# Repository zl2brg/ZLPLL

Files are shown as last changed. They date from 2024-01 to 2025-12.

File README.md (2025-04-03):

# ZLPLL
Wayne Knowles ZL2BKC ZLPLL ZLPLL-14G Code. Imported v4.2A from his avrstudio project and added open source licences along with Linux Makefile build support.
v4.4A Fixed floating point precision register calculation inaccuracies by moving to 64/32bit integer math. 
Register calculations are based on Andy G4JNT's code. Frequency calculation now accurate to 10Hz below 6.8Ghz and 20Hz above.

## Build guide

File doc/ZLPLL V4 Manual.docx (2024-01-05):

# ZLPLL User Guide

Wayne Knowles, ZL2BKC

w.knowles@xtra.co.nz

<< Update Picture >>

# 1 Introduction

The ZLPLL is a frequency agile synthesizer with many unique features designed for use as a local oscillator for amateur radio projects, weak signal source, or an exciter for a CW beacon.

Two versions of the board are currently available depending on frequency requirements with an onboard microprocessor catering for simple configuration of up to 16 frequencies that can be programmed by the end user over a serial interface.

As the programming and interfacing details are similar they are both included in this manual with specific differences between the boards highlighted where appropriate.

# 2 Specifications

Model | ZLPLL TCXO | ZLPLL 14G
PLL | ADF4351 | ADF5355
Frequency Range | 31MHz – 4.4GHz | 62MHz – 13.8GHz (14 GHz with reduced specs)
Power | 8 to 14VDC 150mA | 9 to 14VDC 300mA
Onboard Reference | 26MHz TCXO | None
Stability | Typically +/- 100Hz at 1GHz after 2 minute warmup | Governed by external reference
External Reference | +0dBm to +10dBm Frequency: 10MHz (Default) Custom frequency between 5 and 100MHz set in firmware | +0dBm to +10dBm Frequency: 10MHz (Default) Custom frequency between 5 and 200MHz set in firmware
Phase Noise | Typical Phase noise at 1GHz -85dBc at 100Hz -98dBc at 1kHz -98dBc at 10kHz -106dBc at 100kHz -138dBc at 1MHz | Typical Phase noise at 10GHz
Outputs | 2 outputs at the programmed frequency, 180 degrees apart. | Output 1 = RF Out for 6.8 to 13.4 GHz Output2 = RF Out for 62MHz to 6.8GHz
Output Level | 4 software selectable levels: -3dBm/0dBm/+3dBm and +6dBm | Above 6.8GHz output: Fixed +10dBm to +14dBm Below 6.8GHz output: +7dBm to 2GHz 0dBm at 5.7GHz
Provision for MMIC Amplifier | Yes (SOT-86) on output RF1 Only | No
CW Beacon Exciter Mode | Yes | Yes
Selectable Channels | 16 (Jumpers or BCD Interface) | 16 (Jumpers or BCD Interface)
Frequency Resolution | 1 KHz | 1 KHz (1 Hz planned for a future firmware version)

# 3 ZLPLL TCXO (ADF4351) Performance

## 3.1 Phase Noise

< Updated Picture >

Figure 1 Performance

## 3.2 Output Level

The Output level is dependent on the choice of inductor value in the output stage. The default 8.2nH inductors are suitable for frequency ranges above 1GHz and driving external multipliers.

For applications below 1GHz the inductor can be changed to 47nH which improves the output level for directly driving level 7 mixers up to 2GHz. This optional inductor is supplied with the board and can be fitted on request.

## 3.3 Harmonic Level

The following graph can be used as a guide to determine the level of output for harmonics. As a general rule the lowest odd harmonic should be used to when wanting the highest level output on a given frequency.

## 3.4 Stability

Because the ZLPLL uses an oven controlled xtal oscillator (OCXO) it has excellent frequency stability making this suitable for use on WSJT modes which require excellent stability over a 309 second to 1 minute period (depending on the mode being used).

With stability better than 1x10⁻¹⁰ the frequency error sufficiently allows for reliable frequency operation using all modes (including WSJT) up to 10GHz and potentially higher.

For more stringent frequency requirements an external oscillator such as Rubidium or GPSDO and the stability will be governed by the external reference.

# 4 ZLPLL TCXO (ADF5355) Performance

## 4.1 Phase Noise

Figure 1 Performance

## 4.2 Output Level

# 5 Application Notes

## 5.1 Termination

Ensure both outputs are well matched. If the 2nd output is un-used it should be terminated otherwise oscillations will occur especially at high output levels (L2 and L3).

## 5.2 Power Supply

The on board voltage regulator is capable of operating up to 15V supply voltage. However for supply voltage above 9V the regulator will get very hot and it is advised to solder a small copper or brass strip to improve the heat dissipation.

## 5.3 Warm-up

The recommended warm-up time is 5 minutes after applying power. For applications that demand short to medium term stability such as WSJT modes a warm-up period of 30 minutes is recommended.

When using an external reference no warm-up is required as stability is governed by the external reference.

# 6 Features

## 6.1 Frequency Multiplier Correction

In cases where the LO is followed by a frequency multiplier, in particular when multiplying by an odd number, the resulting frequency may suffer from rounding errors resulting in a small frequency error in the final frequency.

In order to prevent oddball frequencies (eg with 0.3333333 MHz re-occurring) the correct procedure is to set the ‘mult’ multiplier value to 3 and then program in desired frequency for the 3rd harmonic.

Due to limitations of the 8 bit Atmel processor only single precision math is supported in firmware various rounding errors occur after 76 significant digits. To overcome this restriction the “step” parameter can be set to force the rounding to the specified frequency step value. As this workaround is not completely failsafe final confirmation using a frequency counter is recommended if ultimate accuracy is required.

Example: Generate a Frequency of 10368.280 MHz for a beacon using the 3rd Harmonic

mult 3

step 10000

freq 10368.280

save 0

Note: The frequency entered is the final frequency of the harmonic.

## 6.2 Channel Interface

## 6.3 Programming

Programming can be done by connecting a TTL level RS232 interface onto the following pins of J4:

RXD, TXD, and GND

Baud rate: 9600 8 bits No Parity 1 stop bit

The interface levels are 3.3V but the protection circuits allow for 5V levels to also be connected without damage.

A suitable interface is a PL2303 based USB to RS232 converter, or a programming cable for a Yaesu FT8x7 transceiver.

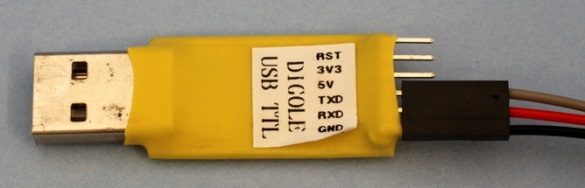
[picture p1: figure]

The labeling of the pins on J4 assumes a DCE interface, thus the RXD pin is an input, and TXD is an output.

Use any terminal program, either TeraTerm, Putty or Hyperterm can be used.

uLO Universal Local Oscillator Rev3.1

(C)2012 W. Knowles, ZL2BKC

d

RF= 1152.000, L=3

Ref= 26.000, N= 0.025

ExtRef= 10.000

Params=23, CP=7

0 RF= 1152.000, L=3

1 RF= 1296.050, L=3

2 RF= 2400.050, L=3

3 RF= 3400.050, L=3

4 RF= 5760.050, L=3, M=3

5 RF=10368.050, L=3, M=3

6 RF= NAN, L=3, M=63

7 RF= 1242.000, L=3

8 RF= 4400.000, L=3

9 RF= NAN, L=3, M=63

10 RF= NAN, L=3, M=63

11 RF= NAN, L=3, M=63

12 RF= NAN, L=3, M=63

13 RF= NAN, L=3, M=63

14 RF= NAN, L=3, M=63

15 RF= NAN, L=3, M=63

The following example demonstrates the commands required to program channel 0 (the default if no channel switch installed) for 1920MHz:

M1

L3

F1920

S0

## 6.4 Command Reference

Note: Commands are not case sensitive

Command | Units | Description
freq ##.# | MHz | Set the output frequency to the specified value in MHz. Decimal numbers are permitted
level # | | Set the output attenuator level. 0 = Minimum (typically -3dBm) 1 = typically 0dBm 2 = typically +3dBm 3 = Maximum (typically +6dBm) Note for the >6.8GHz output on the ZLPLL14G board the level command is ignored and maximum output level is generated, typically > +10dBm
mode # | | Set operating mode. 0 = RF Output disabled 1 = RF Output Enabled (LO Mode) 2 = CW Beacon mode. RF Output keyed with message 3 = CW Beacon mode. RF Output enabled with external keying
save # | | Save current setup to memory channel #
channel # | | Recall settings from memory channel #
ref_int ## | MHz | Set frequency of internal reference. For ZLPLL this should be set to 26 MHz
ref_ext ## | MHz | Set frequency of external reference in MHz. Default frequency is 10 MHz, but can be changed to any value between 5 and 100MHz
show | | Display current configuration details
step # | Hz | Not supported
rdiv # | | Reference frequency divisor. This should be set to 1 unless the loop filter components have been changed.
config mtld # | | Mute to lock detect option. If the PLL is unlocked the RF Output will be disabled. 0=MTLD disabled 1=MTLD enabled
config spur # | | Spur reduction mode 0 = Spur reduction disabled (lower Phase Noise) 1 = Spur reduction enabled (higher pahse noise)
config bleed # | | ZLPLL 14G Only: Configure the loop filter bleed current. Value is typically between 10 and 20 for best performance
config cp # | | Phase Detector charge pump current.
config dblr_max # | | Frequency which the internal doubler is enabled on the reference input (either internal or external). Refer to the PLL datasheet
config ref_level # | | Sensitivity level for external reference input. Default value = 10
cw text | | Enter the CW Message used for beacon mode transmissions (using mode=2 or mode=3)
cal | | Enter TCXO Calibration routine.
adc | | Diagnostic: Show levels of ADC input pins
diag | | Diagnostic: Display PLL register values and frequency errors

Note the frequency changes are volatile and must be saved using the save command if you require settings to be persistent.

## 6.5 Frequency Calibration

## 6.6 Diagnostics

The ADC command dumps the measured voltages of the

## 6.7 Status LED’s

LED | Name | Colour | Description
LED1 | Aux | Amber | Power Up Permanently on to indicate self test failed Standard LO Mode Indicates the External Reference has been selected CW Mode Flashes to indicate the Key Down condition
LED2 | Lock | Green | Indicates the PLL is in a locked condition

At power up the Lock LED will flash 3 times while running power up diagnostics. If the diagnostic passes the Green Lock LED will stay lit to indicate the PLL has passed self tests and is locked.

If any of the self tests fail the Amber Aux LED will stay permanently on and if the PLL has achieved Lock condition despite the fault the Green Lock LED will light.

For the TCXO version of the ZLPLL when an external reference is connected the Aux LED will flash for 3 seconds indicating the reference signal has been detected and stay lit to indicate the external reference has been detected. If a lock issue occurs using an external reference the firmware till revert back to the on board reference until it sees the reference removed and reapplied.

## 6.8 Initial Programming

Several parameters have default settings, and if they are accidentally overwritten the performance of the board may be limited.

To reprogram the default settings, enter:

Ext_ref 10

Int_ref 26

Freq 1152

Level 3

Save 0

# 7 Special Applications

The board is designed to cater for several end user applications. Some of the applications are outlined in this section.

## 7.1 TX Offset

For some applications the LO frequency needs to be changed during transmit, for example generating a 20MHz repeater offset for a 1296 to 144MHz transverter.

When the TX line (shared with RS232 input) is pulled low the channel number is automatically increased by 8, or decreased by 8 for channels above 8.

## 7.2 Sharing LO between 2 Tranverters

In order to reduce construction costs and maximize the use of space many constructors opt to share a single LO across multiple bands. Given the PLL board contains 2 LO outputs there is a natural instinct to use these for driving multiple transverters

If the LO frequency requirement is different for each transverter the TX input can be dropped to a logic LOW which results in 8 being added to the channel number, where the different LO frequency has been setup.

Note: The interface is 3.3V logic with a pull-up to logic 1. In most cases a suitable interface circuit may need to be added externally using a NPN transistor or similar.

# 8 Experimental Options

## 8.1 2nd RF Output

The ADF4351 PLL chip provides 2 outputs with a phase difference of 180°. To enable the 2nd output remove R18 and install a 1206 0R jumper into location LPF2 and install the SMA connector.

Parts to add this option are supplied with the board.

## 8.2 Low Frequency operation

The ADF4350 and ADF4351 datasheets recommend different output inductors depending on frequency range. If you require a few more dB of output on the lower frequencies then the inductors L4 and L5 can be changed as follows:

Frequency Range | L4 and L5 Inductor Values
137 to 500MHz | 100nH
500 to 1000MHz | 47nH
1000 to 2000MHz | 7.5nH
2000 to 4400MHz | 3.9nH

As supplied a 3.9nH inductor is installed suitable for > 2000 operation, and replacement inductors are supplied if more output power is required on lower frequencies.

Details of the expected power levels are shown in section 3.2

## 8.3 10MHz Filter Option

The external reference input at the PLL is a high impedance and extremely sensitive to external noise, or aliasing used on DDS reference. An optional 10MHz Xtal can be installed in location X1 if more filtering is required.

Note that the input resistor R10, 49.9Ω may be removed to increase level by 3dB .

## 8.4 Low Pass Filter

When driving a frequency multiplier the LO harmonics generated are critical for producing a large signal after multiplication. However there are design applications where no multiplication is required and if there is insufficient filtering before the mixer this can result in unwanted images. For such applications a Minicircuits LFCN series Low Pass filter can be substituted with the 0Ω 1206 jumper installed in location LPF1 and LPF2.

## 8.5 Disable on-board oscillator power-down

When an external reference is detected the internal oscillator is powered down for 2 reasons:

1. Power Reduction (saving approx. 50mA)
2. Reduce cross talk from internal oscillator which causes unwanted spurs

When the external oscillator is removed the internal reference starts from cold again and requires several minutes to warm-up, and 30 minutes to be become completely stable. By installing a 0Ω jumper in location R6 the internal reference is never powered off.

# 9 CW Beacon Firmware

All boards feature the CW Beacon firmware by default. This is enabled by selecting mode 2 which is saved as part of the memory channel configuration.

When the message finishes it will loop back to the beginning with no delay, so inserting a space or delay is recommended.

The maximum message length is 100 characters

2 special characters are used to control the carrier as follows

Character | Purpose
^ | Send 1 second with carrier down
_ (underscore) | Wait 1 second with no carrier

## 9.1 Special Considerations

Due to the high frequency of the PLL chipsets the RF output has an extremely fast rise/fall time which ultimately results in a wide bandwidth “glitch” which amateur radio stations refer to as key clicks. On lower bands with higher channel densities and intermod potential it is desirable to implement envelope shaping to control key clocks. This cannot be done by the ZLPLL itself, however timing signals are available to interface to external PA’s to control the RF envelope.

The timing parameter t1 and t2 set the delay are as follows

<< Diagram of key timing >>

When interfacing to an external

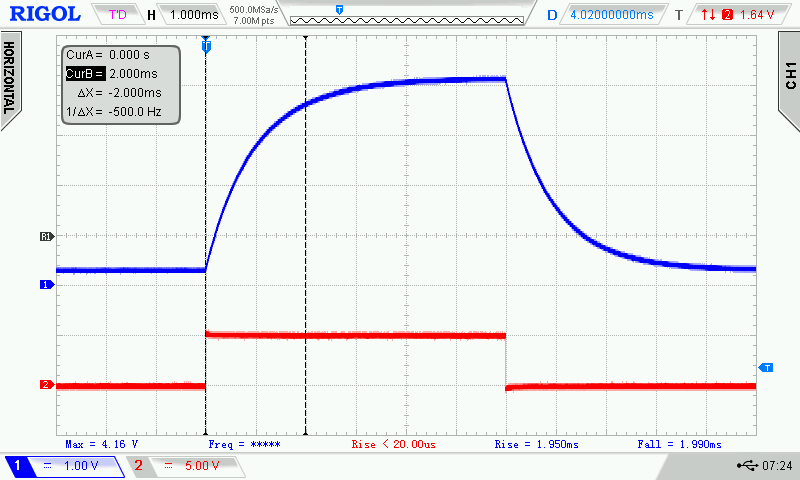
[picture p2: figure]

## 9.2 Configuration example

> cw text [ENTER]

_ZLPLL_EXAMPLE_^^^^^ [ENTER]

>

# 10 External Reference requirements

# 11 Application Notes

## 11.1 LO For 23cm Transverter

## 11.2 LO for 76GHz transverter

## 11.3 LO for 122GHz transverter

The narrowband segment of the 122GHz amateur band (2.5mm) starts at 122.250 GHz. One recommended lineup uses surplus 38GHz triplers (such as the CMA 38400 which operates at the required 40.7 GHz) and use the 3rd harmonic in the final mixer.

IF = 144MHz RF = 122250 MHz

Flo = 122106 MHz

FLO/3 (output of 38GHz module) = 40702 MHz

FLO/9 (input to 38GHz module) = 13567 1/3 MHz

In order to precisely configure this frequency the following setup is recommended:

freq 122106

multiplier 9

step 20000

save 0

For an IF of 145 MHz

freq 122105

multiplier 9

step 20000

save 0

## 11.4 CW Beacon

# 12 Troubleshooting

# 13 FAQ

## 13.1 Sometimes the frequency is displayed incorrectly

This is a side effect of the single precision math used in the on board micro. With careful use of the step parameter to round the frequency it is possible to control the output frequency however the displayed frequency as seen in the “show” output may be incorrect.

## 13.2 Heat Issues

## 13.3 Spurs

The onboard TXCO of the ZLPLL TCXO version is tuned using a PWM signal which can produce weak spurs about 50kHz each side of the programmed frequency. However they will disappear when using an external reference

Also you may see spurs at the harmonics of the reference frequency, especially if it falls within or near the loop bandwidth of the PLL.

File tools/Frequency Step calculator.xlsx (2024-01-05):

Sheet: Sheet1
Freq: | 2320.857 |  |  |  | 116.04285 | 2320
VCO= | 4641.714
 |  | H(Hz) | Div | Remainder
Div Start | 25 | 2.5e-05 | 92834280 | 0
 | 25.001 | 2.5001e-05 | 92830566.78 | 0.7773288935
 | 26.001 | 2.6001e-05 | 89260297.68 | 0.6808584183
 | 27.001 | 2.7001e-05 | 85954483.17 | 0.1672900915
 | 28.001 | 2.8001e-05 | 82884789.83 | 0.8289346695
 | 29.001 | 2.9001e-05 | 80026792.18 | 0.179580003
 | 30.001 | 3.0001e-05 | 77359321.36 | 0.3559547961
 | 31.001 | 3.1001e-05 | 74863939.87 | 0.8729073107
 | 32.001 | 3.2001e-05 | 72524514.86 | 0.85891065
 | 33.001 | 3.3001e-05 | 70326868.88 | 0.8827611208
 | 34.001 | 3.4001e-05 | 68258492.4 | 0.3972824216
 | 35.001 | 3.5001e-05 | 66308305.48 | 0.4769863635
 | 36.001 | 3.6001e-05 | 64466459.27 | 0.2650204077
 | 37.001 | 3.7001e-05 | 62724169.62 | 0.6170373634
 | 38.001 | 3.8001e-05 | 61073577.01 | 0.01113127917
 | 39.001 | 3.9001e-05 | 59507628.01 | 0.009538203478
 | 40.001 | 4.0001e-05 | 58019974.5 | 0.5006374866
 | 41.001 | 4.1001e-05 | 56604887.69 | 0.685666196
 | 42.001 | 4.2001e-05 | 55257184.35 | 0.3527534977
 | 43.001 | 4.3001e-05 | 53972163.44 | 0.4380595759
 | 44.001 | 4.4001e-05 | 52745551.24 | 0.2374718636
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

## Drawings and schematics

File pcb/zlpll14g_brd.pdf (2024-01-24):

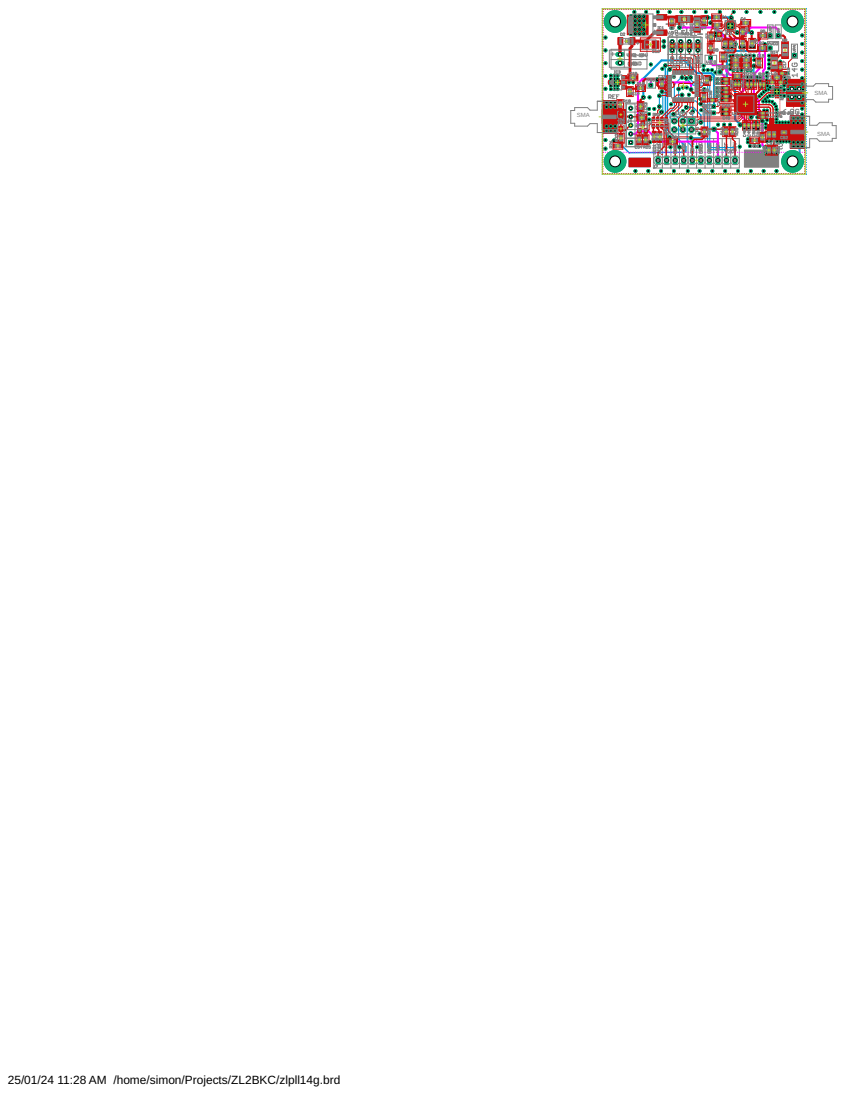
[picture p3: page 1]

25/01/24 11:28 AM /home/simon/Projects/ZL2BKC/zlpll14g.brd

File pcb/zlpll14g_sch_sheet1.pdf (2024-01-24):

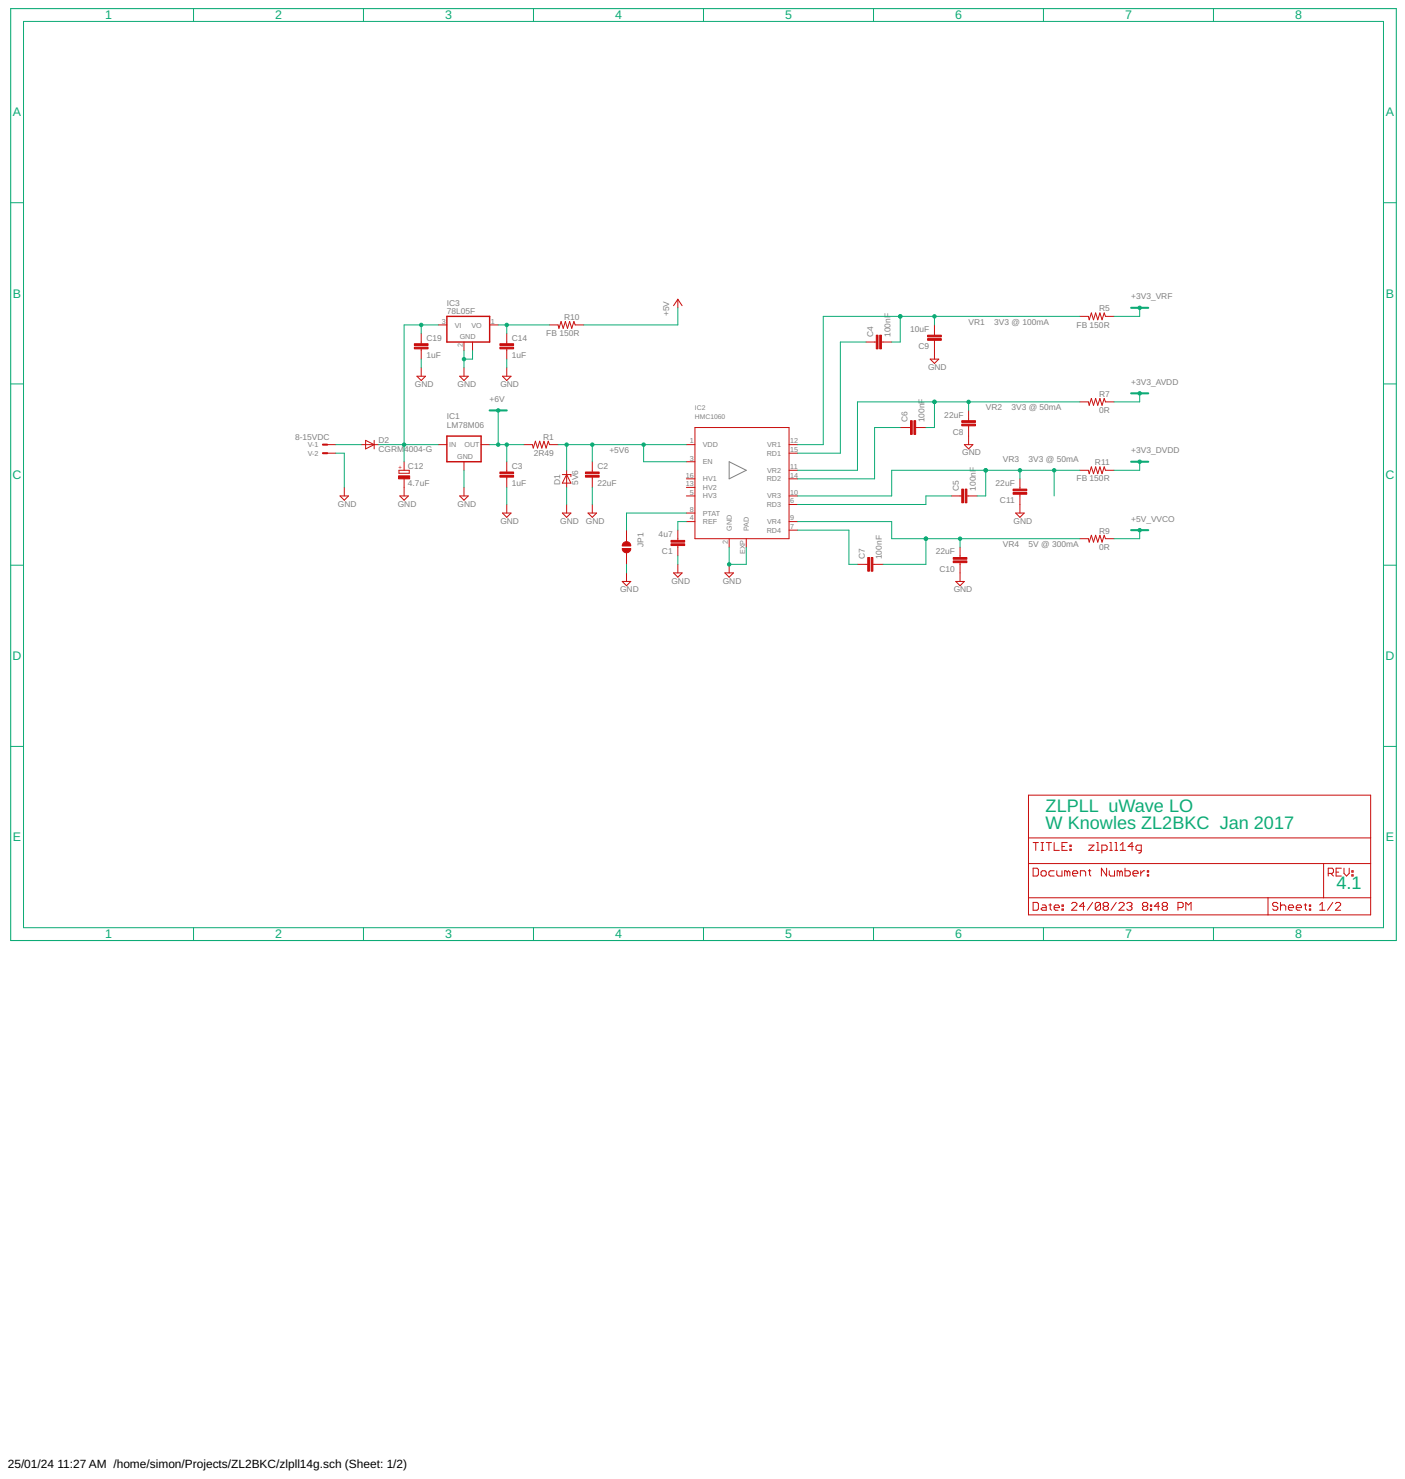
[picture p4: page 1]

25/01/24 11:27 AM /home/simon/Projects/ZL2BKC/zlpll14g.sch (Sheet: 1/2)

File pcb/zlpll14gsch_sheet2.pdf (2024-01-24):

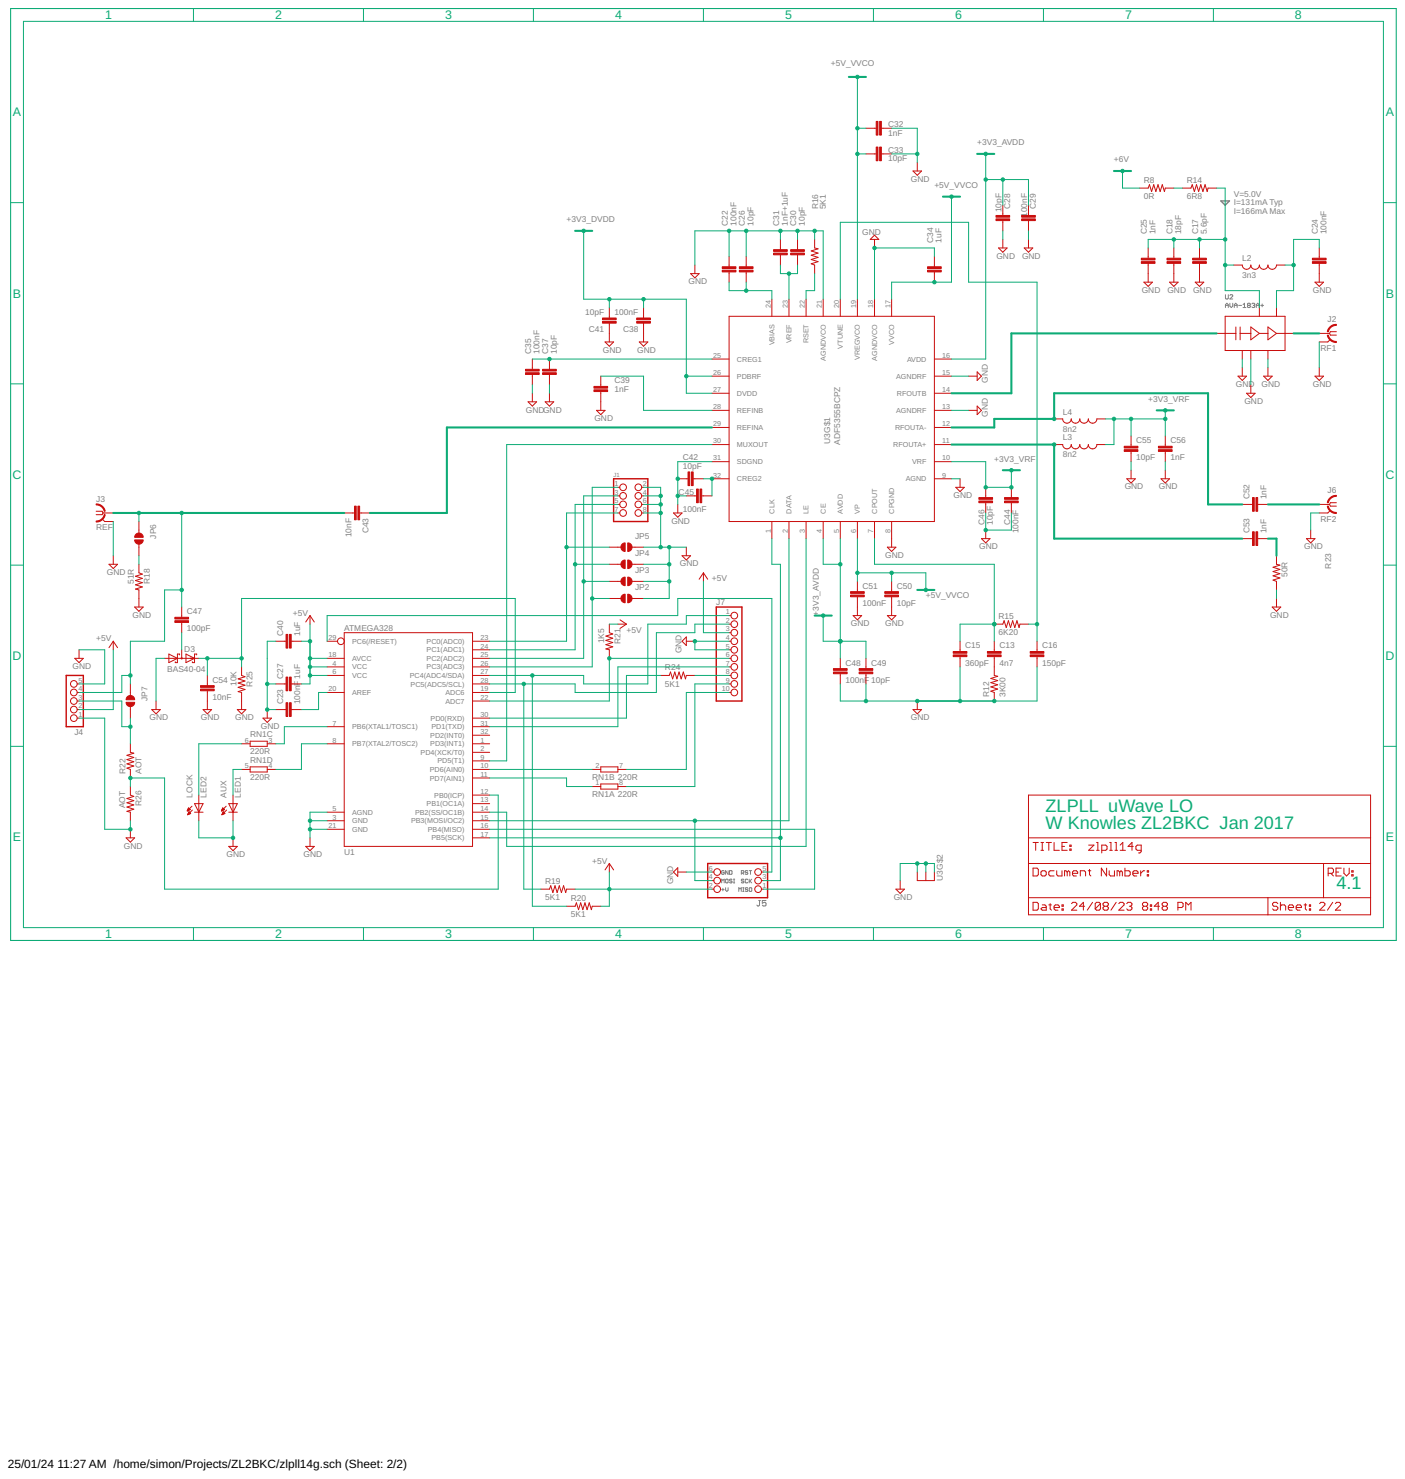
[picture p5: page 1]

+5V_VVCO

3 4
5 6
7 8

ATMEGA328 | | 2

25/01/24 11:27 AM /home/simon/Projects/ZL2BKC/zlpll14g.sch (Sheet: 2/2)

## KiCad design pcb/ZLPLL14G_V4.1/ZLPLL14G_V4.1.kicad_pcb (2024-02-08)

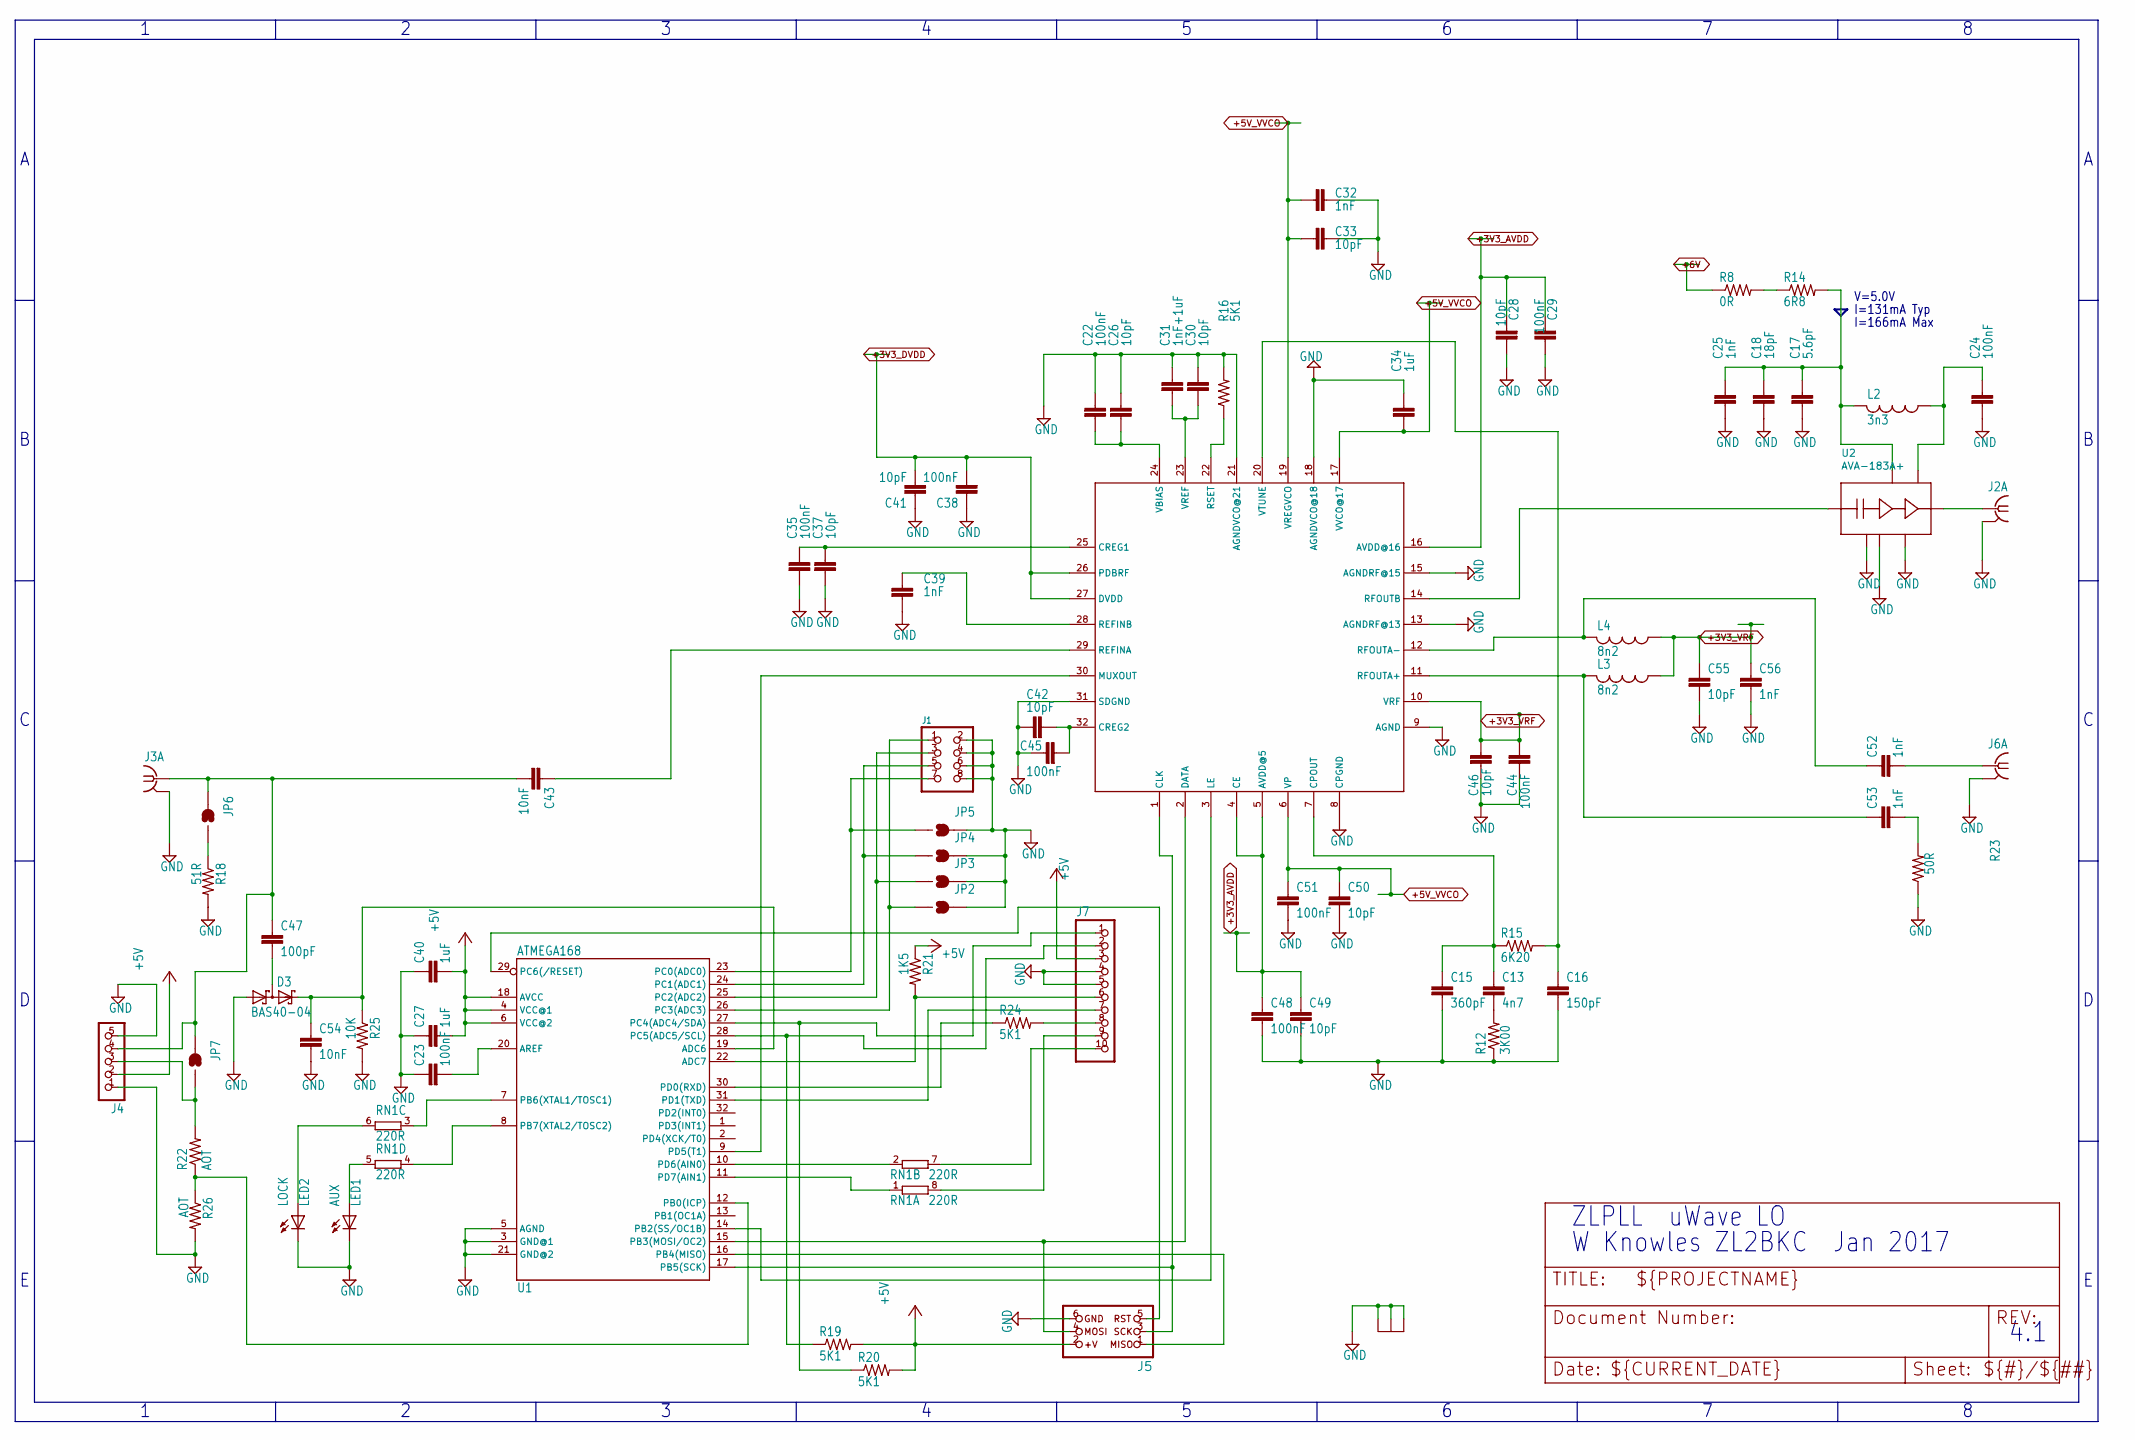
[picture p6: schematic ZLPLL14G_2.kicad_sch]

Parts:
C13: 4n7; C0603
C15: 360pF; C0603
C16: 150pF; C0603
C17: 5.6pF; C0402
C18: 18pF; C0402
C22, C24, C29, C35, C38, C44, C45, C48, C51: 100nF; C0402
C23: 100nF; C0603
C25, C32, C39: 1nF; C0402
C26, C28, C30, C33, C37, C41, C42, C46, C49, C50: 10pF; C0402
C27, C40: 1uF; C0603
C31: 1nF+1uF; C0402
C34: 1uF; C0402
C43, C54: 10nF; C0603
C47: 100pF; C0603
C52, C53, C56: 1nF; C0603
C55: 10pF; C0603
D3: BAS40-04; SOT23
J1: CON_HEADER_2X04-PTH; M2X4
J2: SMA-J797
J3, J6: SMA-142-0711-821/826; J502-ND-142-0711-821_826
J4: CON_HEADER_1X05-PTH; M1X5
J5: CON_HEADER_PRG_AVR_ICSP-PTH; HEADER_PRG_2X03
J7: PINHD-1X10; 1X10
JP2, JP3, JP4, JP5, JP7: SOLDERJUMPERNO; SJ_2S-NO
JP6: SOLDERJUMPERNC2; SJ_2S-NOTRACE
L2: 3n3; C0603
L3, L4: 8n2; C0603
LED1: AUX; CHIPLED_0805
LED2: LOCK; CHIPLED_0805
R8: 0R; R1206
R12: 3K00; R0603
R14: 6R8; R1206
R15: 6K20; R0603
R16, R19, R20, R24: 5K1; R0603
R18: 51R; R0603
R21: 1K5; R0603
R22, R26: AOT; R0603
R23: 50R; R0603
R25: 10K; R0603
RN1: 220R; EXBS8V
U1: ATMEGA168; TQFP32-08
U2: AVA-183A+; DQ849
U3: ADF5355; QFN50P500X500X100-33V2N

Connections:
+3V3_AVDD: C28.2, C29.2, C48.1, C49.1, U3.4 (CE), U3.5 (AVDD@5), U3.16 (AVDD@16); also elsewhere on the board
+3V3_DVDD: C38.2, C41.2, U3.26 (PDBRF), U3.27 (DVDD); also elsewhere on the board
+3V3_VRF: C44.1, C46.1, C55.1, C56.1, L3.1, L4.1, U3.10 (VRF); also elsewhere on the board
+5V: C27.2, C40.2, J4.2, J5.2 (+V), J7.3, R19.2, R20.2, R21.1, U1.4 (VCC@1), U1.6 (VCC@2), U1.18 (AVCC); also elsewhere on the board
+5V_VVCO: C32.2, C33.2, C34.2, C50.1, C51.1, U3.6 (VP), U3.17 (VVCO@17), U3.19 (VREGVCO); also elsewhere on the board
+6V: R8.1; also elsewhere on the board
GND: C15.2, C16.2, C17.2, C18.2, C22.1, C23.1, C24.2, C25.2, C26.1, C27.1, C28.1, C29.1, C30.1, C31.1, C32.1, C33.1, C34.1, C35.2, C37.2, C38.1, C39.2, C40.1, C41.1, C42.1, C44.2, C45.1, C46.2, C48.2, C49.2, C50.2, C51.2, C54.2, C55.2, C56.2, D3.1 (A1), J1.2, J1.4, J1.6, J1.8, J2.GND@1 (GND), J2.GND@2 (GND@1), J2.GND@3 (GND@2), J2.GND@4 (GND@3), J2.GND@5 (GND@1), J2.GND@6 (GND@2), J2.GND@7 (GND@3), J3.G@1 (GND), J3.G@2 (GND@1), J3.G@3 (GND@2), J3.G@4 (GND@3), J4.1, J4.5, J5.6 (GND), J6.G@1 (GND), J6.G@2 (GND@1), J6.G@3 (GND@2), J6.G@4 (GND@3), J7.4, J7.5, JP2.2, JP3.2, JP4.2, JP5.2, LED1.C, LED2.C, R12.1, R16.2, R18.2, R23.1, R25.2, R26.2, U1.3 (GND@1), U1.5 (AGND), U1.21 (GND@2), U2.1 (GND@1), U2.6 (GND@2), U2.PAD (GND), U3.8 (CPGND), U3.9 (AGND), U3.13 (AGNDRF@13), U3.15 (AGNDRF@15), U3.18 (AGNDVCO@18), U3.21 (AGNDVCO@21), U3.31 (SDGND), U3.PAD@1_1 (GND@1), U3.PAD@1_2 (GND@2), U3.PAD@1_3 (GND@3), U3.PAD@2_1 (GND@1), U3.PAD@2_2 (GND@2), U3.PAD@2_3 (GND@3), U3.PAD@3_1 (GND@1), U3.PAD@3_2 (GND@2), U3.PAD@3_3 (GND@3); also elsewhere on the board
unnamed: U1.14 (PB2(SS/OC1B)), U3.3 (LE)
unnamed: C23.2, U1.20 (AREF)
unnamed: J5.5 (RST), U1.29 (PC6(/RESET))
unnamed: R16.1, U3.22 (RSET)
unnamed: J7.8, R24.2
unnamed: J7.7, U1.31 (PD1(TXD))
unnamed: R24.1, U1.30 (PD0(RXD))
unnamed: C52.1, L4.2, U3.12 (RFOUTA-)
unnamed: C43.1, U3.29 (REFINA)
unnamed: C47.2, D3.3 (C1A2)
unnamed: C54.1, D3.2 (C2), R25.1, U1.19 (ADC6)
unnamed: C53.1, L3.2, U3.11 (RFOUTA+)
unnamed: J5.4 (MOSI), U1.15 (PB3(MOSI/OC2)), U3.2 (DATA)
unnamed: C13.2, R12.2
unnamed: J2.PIN (1), U2.5 (OUT)
unnamed: C13.1, C15.1, R15.1, U3.7 (CPOUT)
unnamed: U1.9 (PD5(T1)), U3.30 (MUXOUT)
unnamed: RN1.4 (1), U1.8 (PB7(XTAL2/TOSC2))
unnamed: J5.1 (MISO), U1.16 (PB4(MISO))
unnamed: RN1.2 (1), U1.10 (PD6(AIN0))
unnamed: J5.3 (SCK), U1.17 (PB5(SCK)), U3.1 (CLK)
unnamed: C16.1, R15.2, U3.20 (VTUNE)
unnamed: U2.2 (IN), U3.14 (RFOUTB)
unnamed: JP6.1, R18.1
unnamed: C53.2, R23.2
unnamed: J1.7, JP5.1, U1.23 (PC0(ADC0))
unnamed: C24.1, L2.1, U2.8 (DC8)
unnamed: J7.6, R21.2, U1.22 (ADC7)
unnamed: C22.2, C26.2, U3.24 (VBIAS)
unnamed: C30.2, C31.2, U3.23 (VREF)
unnamed: C52.2, J6.1
unnamed: R8.2, R14.1
unnamed: J4.3, JP7.1, R22.2
unnamed: R22.1, R26.1, U1.12 (PB0(ICP))
unnamed: J1.5, JP4.1, U1.24 (PC1(ADC1))
unnamed: J1.3, JP3.1, U1.25 (PC2(ADC2))
unnamed: J1.1, JP2.1, U1.26 (PC3(ADC3))
unnamed: J7.1, R20.1, U1.27 (PC4(ADC4/SDA))
unnamed: J7.2, R19.1, U1.28 (PC5(ADC5/SCL))
unnamed: C43.2, C47.1, J3.1, J4.4, JP6.2, JP7.2
unnamed: RN1.3 (1), U1.7 (PB6(XTAL1/TOSC1))
unnamed: RN1.1, U1.11 (PD7(AIN1))
unnamed: LED1.A, RN1.5 (2)
unnamed: LED2.A, RN1.6 (2)
unnamed: J7.9, RN1.8 (2)
unnamed: J7.10, RN1.7 (2)
unnamed: C17.1, C18.1, C25.1, L2.2, R14.2, U2.7 (DC7)
unnamed: C35.1, C37.1, U3.25 (CREG1)
unnamed: C39.1, U3.28 (REFINB)
unnamed: C42.2, C45.2, U3.32 (CREG2)

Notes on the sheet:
I=166mA Max
V=5.0V
ZLPLL uWave LO
I=131mA Typ
W Knowles ZL2BKC Jan 2017
4.1

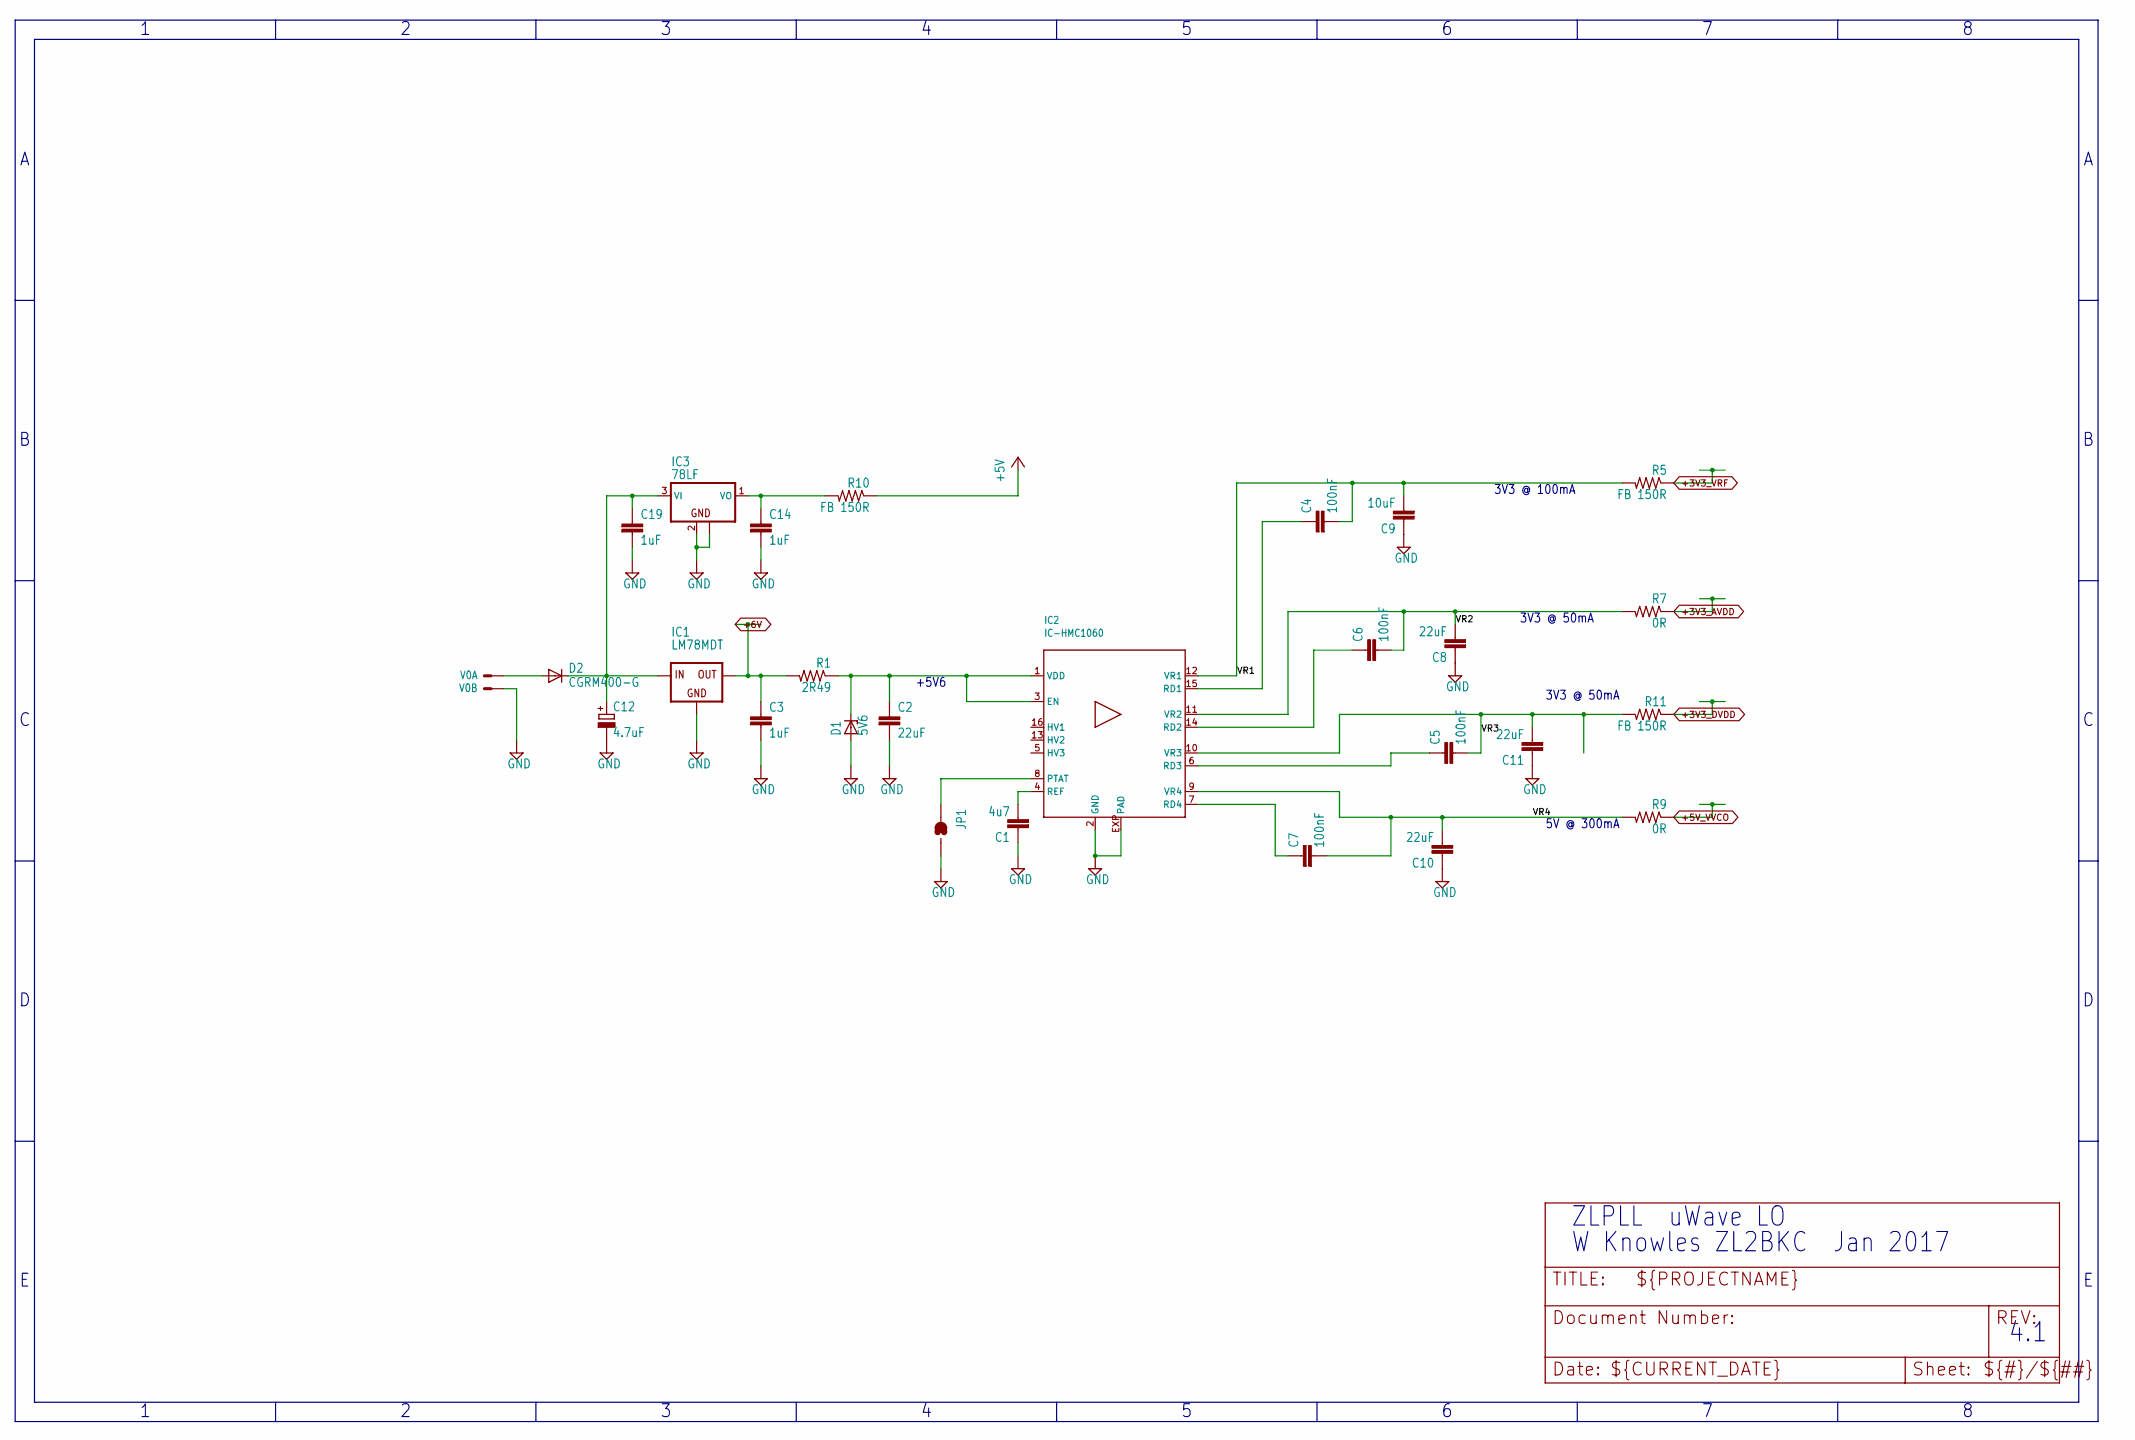
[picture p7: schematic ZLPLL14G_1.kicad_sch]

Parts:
C1: 4u7; C0603
C2, C8, C10, C11: 22uF; C0603
C3, C14, C19: 1uF; C0603
C4, C5, C6, C7: 100nF; C0603
C9: 10uF; C0603
C12: 4.7uF; CT3528
D1: 5V6; SOD80C
D2: CGRM400-G; SOD-123_MINI-SMA
IC1: LM78MDT; DPACK
IC2: IC-HMC1060; QFN16
IC3: 78LF; SOT89
JP1: SOLDERJUMPERNO; SJ_2S-NO
R1: 2R49; R1206
R5, R10, R11: FB 150R; R0603
R7, R9: 0R; R0603
V0: 22-23-2021

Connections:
+3V3_AVDD: R7.1; also elsewhere on the board
+3V3_DVDD: R11.1; also elsewhere on the board
+3V3_VRF: R5.1; also elsewhere on the board
+5V: R10.1; also elsewhere on the board
+5V_VVCO: R9.1; also elsewhere on the board
+6V: C3.1, IC1.3 (OUT), R1.2; also elsewhere on the board
GND: C1.1, C2.2, C3.2, C8.1, C9.1, C10.1, C11.1, C12.-, C14.2, C19.2, D1.A, IC1.4 (GND), IC2.2 (GND), IC2.EXP (PAD), IC3.2 (GND), IC3.2@1 (GND@1), JP1.1, V0.2; also elsewhere on the board
unnamed: C2.1, D1.C, IC2.1 (VDD), IC2.3 (EN), R1.1
unnamed: C12.+, C19.1, D2.C, IC1.1 (IN), IC3.3 (VI)
unnamed: C7.1, IC2.7 (RD4)
unnamed: D2.A, V0.1
unnamed: C14.1, IC3.1 (VO), R10.2
unnamed: IC2.8 (PTAT), JP1.2
unnamed: C4.1, IC2.15 (RD1)
unnamed: C6.1, IC2.14 (RD2)
unnamed: C5.1, IC2.6 (RD3)
unnamed: C1.2, IC2.4 (REF)
VR1: C4.2, C9.2, IC2.12 (VR1), R5.2
VR2: C6.2, C8.2, IC2.11 (VR2), R7.2
VR3: C5.2, C11.2, IC2.10 (VR3), R11.2
VR4: C7.2, C10.2, IC2.9 (VR4), R9.2

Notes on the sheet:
3V3 @ 50mA
ZLPLL uWave LO
+5V6
W Knowles ZL2BKC Jan 2017
5V @ 300mA
3V3 @ 100mA
4.1

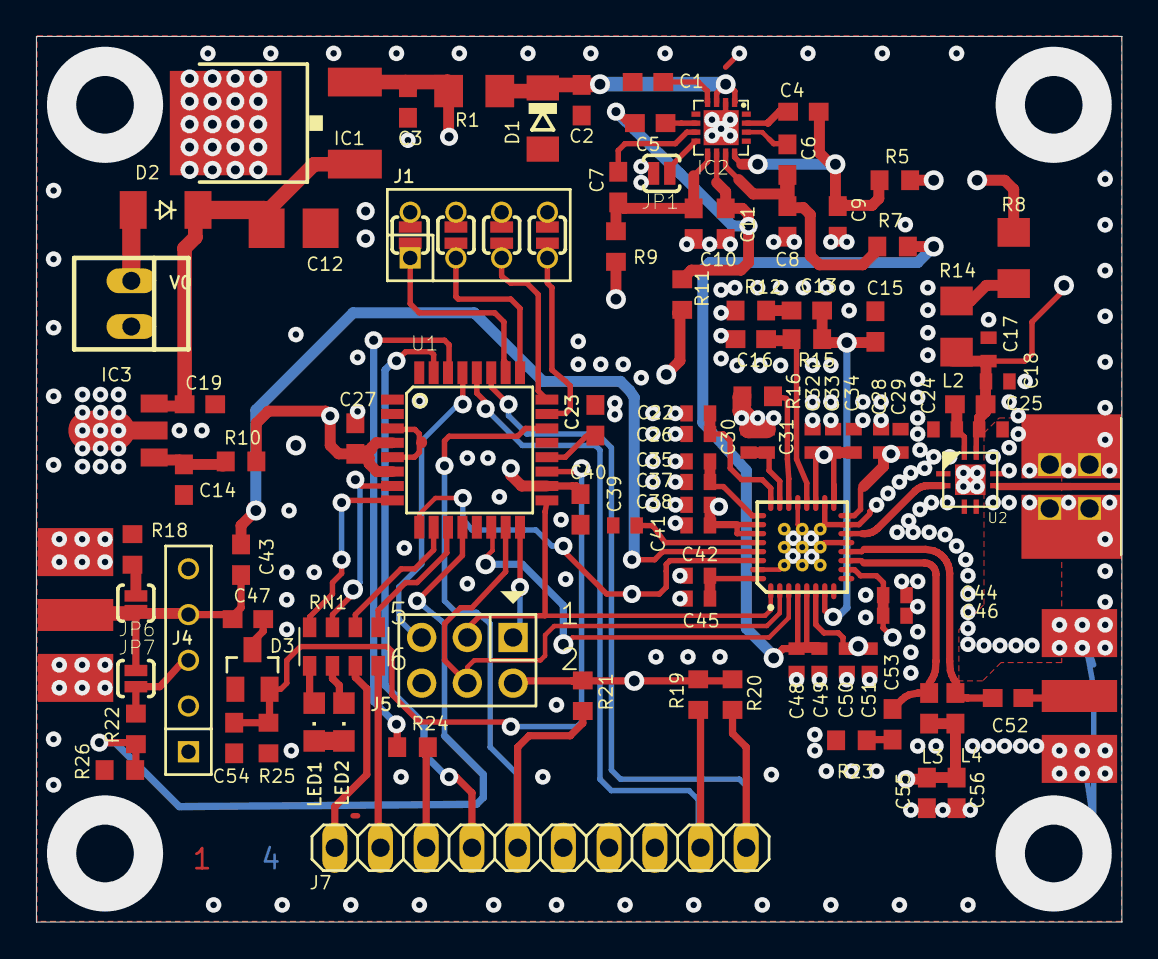
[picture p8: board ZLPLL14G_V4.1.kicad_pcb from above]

Board: 4 copper layers, 60.3 x 49.2 mm, 103 parts (0 on the bottom side), 71 nets.

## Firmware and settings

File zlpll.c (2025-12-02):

/*
 *  PLL Synthesized Local Oscillator
 *
 *  ADF435x version
 *
 *   Copyright (C) 2008-2023 Wanye Knowles ZL2BKC,2025 Simon Eatough ZL2BRG
 *
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
*
*/
// Rev 3.0
// Rev 3.1
//
// Rev 3.1A 	WDK	20-Jan-2013
//	- Change sense of oscillator select output to cater for added BC847
//	  Inverter driving the oscillator power switch.
//      - Allow space in command (ie F 2200)
//
//	PCB includes pins to take lock and ext signals to external LED's
//
// Rev 3.1B	WDK	10-Mar-2013
//	- Restructure to allow for Beacon ID version
//	- Internal version only
//
// Rev 3.1C     WDK     23-Mar-2013
//      - Multiple channel support
//	- Fixed bugs with I/O pins
//	- Stopped transmitting when text entered
//	- Test for bad messages, ie [0] by itself which looped!
//
// Rev 3.1D	WDK	3-Oct-2013
//	- Frequency set to 0 MHz enables external PLL
//	  support for connection to Multi Beacon Controller (MBC)
//      - Channel spacing (N) changed from MHz to Hz
//
//      - Add V command for setting the RDIV value
//      - Set E to 0 to disable external ref selection
//      - Set R to 0 to disable internal ref selection
//        NB.  Power cycle may be required to change clock modes
//
//  Rev 3.1E 
//		- Improve soft UART receiver to sample data in middle of bit. Fixed issue with
//		  corrupted data on input 
//		- EXT_THRESHOLD improvements to avoid false triggering of external clock 
//		- From S/N 200 (excl 201 and 206) plus S/N 184E 
//
//  Rev 3.1F
//		- Add extra stop bit to support PL2303TX USB/RS232 interface
//		- Change TX output mode to better handle the reading of the channel offset (+8 to the channel)
//
//  Rev 4.0
//		- Fork codebase for ATMega328 controller version
//
//  Rev 4.1
//		- Updated board design.  Lockdetect separated from Muxout pins
//		- Use Timer1 for Muxout
//		- Add LCD and encoder support
//
//  Rev 4.1B
//		- Support for ADF5355
//		- Split code functions to allow support for 2 PLL chips
//		- Add bleed config setting for ADF5355
//
//  Rev 4.1C
//      -  Update help file
//		-  Disable bleed on ADF4351
//	Rev 4.1D
//		-  Fix bug with MUXOUT test that failed if the PLL was unlocked before test started 
//
//  Rev 4.1E
//		-  Fix bug when freq=0 (external program mode) SPI was disabled so a 2nd call to set_freq
//		   would lockup.  More importantly the PLL would not boot when freq=0 by default.
//		-  External programming mode (Multi Beacon controller) when freq <30 MHz
//			mode=0 for external reference, mode=1 for internal
//		-  ADF5355:  *TODO* Support enabling both RF outputs for 2nd conversion IF applications
//
//  Rev 4.1F
//		-   RDIV on ADF5355 board (ZLPLL 14G) used to enable RFA Divisor while RFB (doubler) is active
//			RDIV = divisor for RFA
//  Rev 4.1G
//      -	Bugfix:  RFB Output not keyed in CW Mode
//		-	Verbose mode display in show command (LO, CW, RFON, RFOFF etc)
//	Rev 4.1H
//		-	Bugfix:  RF Multiplier rounding errors with high RF Freq (ie. 75887 with Mult 6)
//
//  Rev 4.2A
//		-	Reference divisor (RDIV) improvements with pfd command.
//	Rev V4.4A
//      - Fixed floating point precision register calculation inaccuracies by moving to 64/32bit integer math. 
//      - Register calculations are based on Andy G4JNT's code. Frequency calculation now accurate to 10Hz below 6.8Ghz and //		- 20Hz above. 
//		- Added range checking for ref frequency
// 
// Rev V4.4B 
//		- Fixed bug in frequency parser and incorrect register 6 divisor setting
// TODO:
//		Check I2C Pullups to stop lockup at power on
//


#include <avr/io.h>
#include <util/delay.h>
#include <avr/eeprom.h>
#include <stdlib.h>
#include <stdio.h>

#include <avr/interrupt.h>
#include <avr/pgmspace.h>
#include <avr/wdt.h>
#include <avr/power.h>
#include <avr/sleep.h>

#include "zlpll.h"
#include "usart.h"
#include "lcd.h"
#include "twi.h"
#include "cw.h"
#include "encoder.h"
#include "menu.h"
#include "config.h"


#if SWEEP
float  step, end_freq, start_freq;
uint16_t time_step;
uint16_t sweep;
#endif
uint8_t channel;

uint8_t clkmode;
volatile uint8_t extcnt;
volatile uint8_t load_freq;

uint16_t	intcnt=100;

#if CW_BEACON
uint8_t  cw_bits=1, key_down;
uint16_t dotlen;
uint8_t *cw_msgp, *cw_msgstart;
uint8_t cw_msgtype;
#endif

//  Valid values for the rf.mode settings
//
//  Note that bit 0 = RF on/off status
//            bit 1 = LO(0) / CW Mode(1)
//			  bit 2 = Sweep enable bit
//
#define	MODE_LO_RFOFF		0		// 0b000
#define MODE_LO_RFON		1		// 0b001
#define MODE_CW_RFKEY		2		// 0b010
#define MODE_CW_RFON		3		// 0b011
#define MODE_SWEEP			5		// 0b101

#define MODE_RFON_BIT			0b001
#define MODE_BEACON_BIT			0b010

//  Delayed operation for keying RF envelope during CW keying
uint8_t  opdelay;
uint8_t  delayed_op;
#define CARRIER_NOP		0
#define CARRIER_KEYON	1
#define CARRIER_KEYOFF	2
#define CARRIER_RFON	3
#define CARRIER_RFOFF	4


uint16_t t1sec, ticks, tick4;
uint8_t  auxled_pattern;		// FIFO for Aux LED updated 4 times per second
uint8_t  reference_state;		// State of reference			
#define  REF_INTERNAL		0	// Internal reference
#define  REF_EXTWAIT		1	// Loss of lock detected
#define  REF_EXTERNAL		2	// External Reference
#define  REF_EXTFAIL		4	// Lock failure when in external mode

uint8_t  extref_count;			// counter for external ref active

uint8_t  softint_1sec, softint_timer;
uint32_t hr_cnt;

uint8_t	 debug_I2C = 0;
uint8_t  debug_PLL = 0;
uint8_t  debug_REF = 0;
uint8_t  debug_CHAN = 0;

uint8_t	 lcd_active, dial_active;



#define TIME_1SEC	(t1sec)  // 1 second of interrupts

void set_freq(uint32_t);
void rf_envelope(uint8_t op);
void set_rflevel(int8_t enable, int8_t level);

struct config_data cf;
struct zlpll_data  rf;
PLL_t	PLL;

#define EEPROM_TEXT1	100    	// EEPROM location for Beacon text
#define EEPROM_TEXT2	200    	// EEPROM location for Beacon text
#define EEPROM_TEXT3	300    	// EEPROM location for Beacon text
#define EEPROM_TXTEND	400	// Room for 400 Bytes message
#define TEXT_MAXLEN		98

#define EEPROM_HOURS	410
#define EEPROM_PWRON	414

#define EEPROM_CHAN		512		// Start of per-channel frequency data



void SPI_Init(void)
{
	//
	// Configure SPI Master Mode
	//
	// **IMPORTANT**
	//
	// The SS pin must be programmed as a output otherwise the SPI
	// controller waits for the pin to become active before sending
	//

//	power_spi_enable();

	OUTPUT(ADF4351_DATA);		// Setup SPI pins for output
	OUTPUT(ADF4351_CLK);
	OUTPUT(ADF4351_LE);
	CLR(ADF4351_LE);

	// Enable SPI, Master Master Mode, Fosc/16
	SPCR = _BV(SPE) | _BV(MSTR) |_BV(SPR0); //| _BV(CPOL); // _BV(CPHA); // SPI Mode 3
}

void
SPI_MasterTransmit(char cData)
{
	SPDR = cData;

	while(!(SPSR & _BV(SPIF)))
		{ /* NOP */ }
	(volatile void) SPDR;
}

void eeprom_increment(uint32_t *addr) {
	uint32_t val;

	val = eeprom_read_dword(addr);
	val++;
	eeprom_write_dword(addr, val);
}

int16_t adc_read(uint8_t mux)
{
	if (mux == 8) {
			ADMUX=_BV(REFS1)|_BV(REFS0);   // Vref=1.1V for reading internal temperature
	} else {
			ADMUX=_BV(REFS0);           // For Aref=AVcc;
	}
	
	ADCSRA=_BV(ADEN)|_BV(ADPS2)|_BV(ADPS1); // Prescalar div factor = 64 for 8MHz FCPU

	ADMUX |= mux & 0x1f;

	ADCSRA|=(1<<ADSC);
	while(!(ADCSRA & (1<<ADIF)));
	
	ADCSRA|=(1<<ADIF);
	return ADC;
}

// Read the channel select input and convert the voltage to the 
// closest channel number
static uint8_t KV[] = {255,197,222,177,237,186,208,168,246,191};
int8_t chan_read(uint8_t mux)
{
	uint8_t adcval, i, key, k, off;

	key = ~PINC & 0x0f;
	return key;
	
	adcval = adc_read(mux) >> 2; // Only need 8 bits
	//PRINTLN("ADC: %x", adcval);
	key = 0;
	k = 255;
	for (i=0; i<10; i++) {
		off = abs(adcval - KV[i]);
		if (off <= k) {
			k = off;
			key = i;
		}
	}	
	return key;
}

void crlf()
{
	putchar('\n');
}

uint16_t GCD(uint16_t a, uint16_t b)
{
	uint16_t c;
	while(1)
	{
		c = a%b;
		if (c==0)
			return b;
		a = b;
		b = c;
	}
}

#if CW_BEACON

void key_cw(uint8_t offon) {
	if (offon) {
		if (cf.t1 > 0) {
			rf_envelope(CARRIER_RFON);
			delayed_op = CARRIER_KEYON;  opdelay = cf.t1;
		} else { // t1 <= 0
			rf_envelope(CARRIER_RFON);
			rf_envelope(CARRIER_KEYON);
		}
	} else {
		if (cf.t2 > 0) {
			rf_envelope(CARRIER_KEYOFF);
			delayed_op = CARRIER_RFOFF;  opdelay = cf.t2;
		} else { // t2 <= 0
			rf_envelope(CARRIER_KEYOFF);
			rf_envelope(CARRIER_RFOFF);
		}
	}
}

struct t_mtab { char c, pat; } ;
struct t_mtab morsetab[] = {
	{'^', 255},  // Carrier on for 1 second
	{'_', 254},  // Carrier off for 1 second

	{'.', 106},	{',', 115},	{'?', 76},	{'/', 41},	{'A', 6},	{'B', 17},	{'C', 21},	{'D', 9},
	{'E', 2},	{'F', 20},	{'G', 11},	{'H', 16},	{'I', 4},	{'J', 30},	{'K', 13},	{'L', 18},
	{'M', 7},	{'N', 5},	{'O', 15},	{'P', 22},	{'Q', 27},	{'R', 10},	{'S', 8},	{'T', 3},
	{'U', 12},	{'V', 24},	{'W', 14},	{'X', 25},	{'Y', 29},	{'Z', 19},	{'1', 62},	{'2', 60},
	{'3', 56},	{'4', 48},	{'5', 32},	{'6', 33},	{'7', 35},	{'8', 39},	{'9', 47},	{'0', 63}
} ;

#define N_MORSE  (sizeof(morsetab)/sizeof(morsetab[0]))

// CW Rate is 1200/W in ms
//
// Interrupt rate = baudrate * 3, ie 28800 for 9600 baud
//
// 1ms = 28.8 ticks, therefore interrupts = 28.8*1200 / W
//

#endif


#if CW_BEACON

void cw_start(uint8_t type, uint8_t *msg, uint8_t delay) {
	uint8_t cw_wpm;
	cw_wpm = cf.cw_speed;
	if (cw_wpm < 5 || cw_wpm > 50)
		cw_wpm = 12;
	dotlen = ((t1sec+t1sec/5)/cw_wpm);  // 1200 ms per dot length

	cw_msgtype = type;
	cw_msgp = cw_msgstart = msg;
	
	if (delay == 0)		//  Delay can't be zero as this stops interrupts and CW is disabled
		delay = 5;
	
	// If running beacon mode setup delay of about 5 secs before sending first bit
	intcnt = rf.mode & MODE_BEACON_BIT ? dotlen*delay:0;
}

void cw_stop(uint8_t rfon) {
		intcnt = dotlen = 0;		// Disable CW Mode
		key_cw(rfon);				// Carrier ON
}
	
uint8_t cw_getchar(void)
{
	switch (cw_msgtype) {
		case MSGTYPE_EEPROM:	return (eeprom_read_byte(cw_msgp));	break;
		case MSGTYPE_PGMMEM:	return (pgm_read_byte(cw_msgp));	break;
		case MSGTYPE_RAM:		return (*cw_msgp);	break;
	}
	return (' ');
}

uint8_t get_next(void)
{
	uint8_t c;

	c = cw_getchar();

	// EEPROM Messages wrap automatically, and others will stop in idle
	// waiting for next mode to start.   This is mainly for CW acknowledgment
	// messages which should not repeat
	//
	if (c == '~')		// Indefinite carrier off
		return '_';
	if (c == (char)0) {  // Wrap message
		cw_msgp = cw_msgstart;
		c = cw_getchar();
		if (c == 0)
			c = ' ';
		else
			cw_msgp++;
	} else
		cw_msgp++;
	
	return c;
}


// Handle special test of CHAN input
//
// [^MSG]   Send MSG if PINA2 is High
// [_MSG]   Send MSG if PINA2 is Low
//
// [0]	    Set TX Output pin PINA1 Low
// [1]	    Set TX Output pin PINA1 High (+3.3v)
//
uint8_t next_char() {
	uint8_t i;
	uint8_t c, c2;

	c = get_next();
	i = 5;
loop:
	while (c=='[' && --i > 0) {
		c2=get_next();
		if (c2 == '^' || c2 == '_') {
			if (c2 == '^') { c2 = _BV(PINC2); }
			else { c2 = 0; }
			if (c2 != (PINC & _BV(PINC2))) {
				// Read up to closing ] 
				c=get_next();
				while (c != '[' && c != ']')
				c = get_next();
			}
		} 
		else if (c2 == '0') {
			PORTC &=  ~_BV(PINC1);   // TX Pin = Lo
		}
		else if (c2 == '1') {
			PORTC |=  _BV(PINC1);    // TX Pin = High
		}

		if (c2 >= '0' && c2 <= '7') {
			key_cw(0);  // Ensure carrier is off before shifting frequency
			cmd_channel(c2-'0');
		}
		c = get_next();
	}
	if (c == ']') {
		c=get_next(); 
		goto loop;
	}

	for (i=0; i<N_MORSE; i++) {
		if (morsetab[i].c == c) {
			return  morsetab[i].pat ;
		}
	}
	return 1;
}
#endif


void rf_envelope(uint8_t op) {
	switch (op) {
		case CARRIER_NOP:									break;
		case CARRIER_KEYON:  	SET(AUXLED);	SET(LED2);	break;
		case CARRIER_KEYOFF:	CLR(AUXLED);	CLR(LED2);	break;
		case CARRIER_RFON:
					PLL(set_rflevel)(1, rf.level);	//PLL_Write(reg4|(1L<<5));
				break;
		case CARRIER_RFOFF:
					PLL(set_rflevel)(0, 0);			//PLL_Write(reg4&~(1L<<5)); 
				break;
	}
}

// Timer callback interrupt, called from soft serial timer interrupt routine
void timer_callback()
{

#if CW_BEACON

		if (rf.rf_freq == 0)
			return;
		if (key_down) {
			// Have just sent a dot or dash, need to send a gap before
			// the next symbol
			intcnt = dotlen;
			key_cw(key_down=0);
		} else {
			if (cw_bits != 1) {  // More symbol to send
				intcnt = (cw_bits&1)?3*dotlen:dotlen;
				key_cw(key_down=1);
				cw_bits >>= 1;
			} else {  // End of symbol
				cw_bits = next_char();
				if (cw_bits == 1) 
					intcnt = (7+(cf.gap))*dotlen;  // Send a space
				else if (cw_bits > 250) {
					// Special characters
					// ^ = 1 second carrier on
					// _ = 1 second carrier off
					key_cw(cw_bits&1);
					intcnt = TIME_1SEC;
					// Trick into pulling new character after 1 second delay
					// also need to prevent a inter symbol space being inserted
					key_down = 0;
					cw_bits=1;  // trick into pulling next char after timeout
				} else
					intcnt = (2+cf.gap)*dotlen; // Inter-char gap.  ne dotlen already passed
			}
		}
#endif
}

void save_config() {
	eeprom_write_block(&cf,	(char *)(EEPROM_CONF),	sizeof(cf));
}

void set_freq(uint32_t freq) {
	// Disable all timer operations
	softint_timer = 0;
	intcnt = 0;
	opdelay = 0;
	DEBUG(PLL>3, "set_freq(%lu)", freq);

	// We may have been powered down previously and SPI mode disabled.  Ensure SPI mode
	// is enabled again so we can program the PLL
	DEBUG(PLL>4, "SPI_Init");
	SPI_Init();
			
	// Frequency 0 disables the PLL programming and places it into slave mode
	if (freq < 30.0 ) {
		PLL(powerdown)();
		SPCR = 0;		// Disable SPI Master mode
		INPUT(ADF4351_DATA);	INPUT(ADF4351_CLK);		INPUT(ADF4351_LE);
		CLR(ADF4351_DATA);		CLR(ADF4351_CLK);		CLR(ADF4351_LE);
		DEBUG(PLL>4, "SPI_3State");
		
		if (rf.mode == 1)	{
			DEBUG(PLL>1, "REF_INTERNAL");
			clkmode = 0;	// Internal
			CLR(AUXLED);	SET(REFSEL);	SET(OSCPOWER);
		} else {
			DEBUG(PLL>1, "REF_EXTERNAL");
			clkmode = 1;	// External
			SET(AUXLED);	CLR(REFSEL);	CLR(OSCPOWER);
		}
		
#if CW_BEACON
		dotlen = intcnt = 0;
#endif
		return;
	} 

	PLL(set_freq)(freq);		// Initialize PLL
	
#if CW_BEACON
	cw_start(MSGTYPE_EEPROM, (uint8_t *)EEPROM_TEXT1, 20);
#endif

	// If we are running in LO mode then set LED2 (external RF enable)
	//
	if (!(rf.mode & MODE_BEACON_BIT)) {		// LO Mode
		SET(LED2);
		softint_timer = 0;
		intcnt = 0;
		opdelay = 0;		// Cancel special operations timer
	}
	
	//
	//  Reprogramming the PLL results in several transitions of the Lock status
	//  These should new be behind us, so reset the loss lock detector
	//
	_delay_ms(2);
}

// Timer1 interrupts
ISR(TIMER1_COMPA_vect)
{
}

// Timer callback interrupt, called from soft serial timer interrupt routine
ISR(TIMER2_COMPA_vect) // Timer1 compare match interrupt
{
	if (--ticks == 0) {
		ticks = t1sec;		// Reset 1sec counter for next cycle
		softint_1sec++;
	}
	
	// LED ticker is 4 interrupts per second
	if (tick4 && --tick4 == 0) {
		if (auxled_pattern & 1)		SET(AUXLED);
	else							CLR(AUXLED); 
		auxled_pattern >>= 1;		// Update pattern for next flash
		tick4 = t1sec/4;		
	}
	
	// opdelay has higher priority than intcnt, ie. when opdeley is in effect intcnt will
	// not count so the CW symbol length is not truncated
	if (opdelay && --opdelay == 0)
		rf_envelope(delayed_op);
	else if (intcnt && --intcnt == 0) {
		softint_timer++;
	}
}

//  Check lock status of PLL and update locked LED to reflect status
//	Returns:  0 = Unlocked
//			  1 = Locked
uint8_t check_pll_locked() {
	uint8_t islocked;
	
	islocked = ISSET(LOCKINPUT); // && (TCNT0 == 0);
	// Update Lock status LED's
	if (islocked)	{ SET(LOCKLED);	SET(LED1); }	// PLL is locked
	else 			{ CLR(LOCKLED); CLR(LED1); }	// PLL is unlocked

	//TCNT0 = 0;		// Reset lock loss counter
	return islocked;
}

#if PWM_ENABLE
void PWM_init() {
		// Output OC1A controls the TCXO frequency
		// Uses 16bit Frequency/Phase PWM mode which feeds a low pass filter
		// with Fc < 22Hz to generate the tuning voltage for the TCXO

		OUTPUT(PWM_OC1A);		// Configure PWM pin as output
		TCCR1A = _BV(COM1A1) /* | _BV(WGM10) */ | _BV(WGM11);
		TCCR1B = _BV(CS10) | _BV(WGM13);		// Prescale x1, Full 16 bit PWM
}

void PWM_set(uint16_t val, uint16_t top) {
	if (val == 0 || val == top) {
		TCCR1B = TCCR1A = 0;		// Disable PWM
		CLR(PWM_OC1A);				// Toggle low 
	} else {
		OCR1A = val;
		ICR1  = top;
	}
}
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
int
main(void) {
	uint8_t  key;
	char cmd;
	uint8_t  show_prompt;
	char cmdbuf[CMDLEN+1], *cmdp;
	uint8_t  ch;

	wdt_enable(WDTO_2S);
	wdt_reset();

	// OSCCAL = 0xAD;
	
	// LED Output pins
	OUTPUT(LOCKLED);
	OUTPUT(AUXLED);
	OUTPUT(LED1);
	OUTPUT(LED2);
	
	OUTPUT(PIN_TXD);
	INPUT(LOCKINPUT);
	
	OUTPUT(OSCPOWER);		// TCXO oscillator power (MIC2090)
	SET(OSCPOWER);			// Enable TCXO power
	
	OUTPUT(REFSEL);			// Signal to ADG719 PLL Reference switch
	SET(REFSEL);			// 1=Internal reference
	
	PORTC |= 0x0f;			// Channel select pins input with pullups		
	DDRC &= ~0x0f;
	
	eeprom_increment((uint32_t *)EEPROM_PWRON);
	_delay_ms(50);

	//--------------------------------------------------------------------------
#if PWM_ENABLE
	PWM_init();
#endif
	clkmode = 0;

	// --------------------------------------------------------------------------
	//  Serial port configuration
	USART_init((uint16_t)(F_CPU/(BAUD_RATE*16L)));
	stdout = stdin = &usart;
	// --------------------------------------------------------------------------

	PRINTLN("ZLPLL Local Oscillator Rev " VERSION);
	PRINTLN("(C)2008 - 2022 Wayne Knowles ZL2BKC, 2023 - 2025 Simon Eatough ZL2BRG");

	
	// --------------------------------------------------------------------------
	//  SPI Interface to ADF435x PLL Chip
	// --------------------------------------------------------------------------	
	SPI_Init();

	cw_start(MSGTYPE_EEPROM, (uint8_t *)EEPROM_TEXT1, 20);
	opdelay = intcnt = 0;		// CW Off for now
	
	// --------------------------------------------------------------------------
	//  Initialize LCD Interface over I2C
	// --------------------------------------------------------------------------
	lcd_active = 0; //lcdInit();
	wdt_reset();
	if (lcd_active) {
		lcdPrintString_P(PSTR("ZLPLL Rev " VERSION));
		wdt_reset();
		PRINTLN("LCD Found (addr=0x%X)", lcd_active);
	}

	load_config();	
	dial_init();
	menu_init();
#if PWM_ENABLE
	PWM_set(cf.pwmval, cf.pwmtop);
#endif

	rf.level = 3;
	load_freq = cmd = 0;

	reference_state = REF_INTERNAL;

	channel = chan_read(PIN_CHANSW);
	
	cmd_channel(channel);		// Load default frequencies etc.
	rf.mode = MODE_LO_RFOFF;	// Mute RF at power up while diags run
	set_freq(rf.rf_freq);
	
	I2C_Init(cf.i2c_addr);
		
	sei();
	
	//  We cant test PLL If it is setup for external control	
	if (rf.rf_freq >= 30.0 ) {
		pll_test();
	}

#if PWM_ENABLE	
	PWM_init();					// Timer1 has been reconfigured by pll_test()
	PWM_set(cf.pwmval, cf.pwmtop);
#endif
	
	// Timer interrupts using TimerCounter 1
	// (shared with PWM function setup above)
	//--------------------------------------------------------------------------
	ticks = t1sec = 100;		// 
	tick4 = 0;					// Disable AUXLED updating
	init_timer(ticks);
//	TIMSK1 = _BV(OCIE1A); 		// Enable timer interrupt
	//--------------------------------------------------------------------------

	cmd_channel(channel);		// Reload this time with RF enabled		
	set_freq(rf.rf_freq);
	//TCNT0 = 0;		
	
	cmdp = cmdbuf;
	show_prompt=1;
	softint_timer = softint_1sec = 0;
		
	// Display frequency and level on LCD (if active)
	if (lcd_active) {
		lcdClear();
		sprintf_P(cmdbuf, PSTR("%lu MHz"), rf.rf_freq);
		lcdPrintString(cmdbuf);
		lcdGotoXY(0,1);
		sprintf_P(cmdbuf, PSTR("Level: %d"), rf.level);
		lcdPrintString(cmdbuf);	
	}

	I2C_Start();
	
	while (1) {
		wdt_reset();
		_delay_us(50);				// Workaround Power EMI issue 	
		if (softint_timer) {
			timer_callback();
			softint_timer--;
		} else
		if (softint_1sec) {
			every_1sec();			// health checks every second
			softint_1sec--;
			
			ch = chan_read(PIN_CHANSW);
			if (ch != channel) {
				channel = ch;
				DEBUG(CHAN, "Channel=%d", channel);
				cmd_channel(channel);
				set_freq(rf.rf_freq);
			}
		}

		//  Only poll encoder if LCD is detected.  Reduces potential EMI issues
		if (lcd_active) {
			key = dial_read();
			if (key)
				menu_event(key);
		}

		if (show_prompt) {
			PRINT("> ");
			show_prompt = 0;
		}

		I2C_check();
		
		if (USART_rxready()) {
			key = getchar();
			if (key == '\n' || key == '\r') {  // Newline
				putchar('\n');
				*cmdp = (char)0;
				// Sanitize input buffer before executing the command
				for (char *p = cmdbuf; *p; ++p) {
					if (!isprint((unsigned char)*p) && *p != ' ') {
						PRINTLN("Invalid input detected. Command aborted.");
						cmdp = cmdbuf; // Reset buffer
						show_prompt = 1;
						return;
					}
				}
				exec_command(cmdbuf);
				show_prompt = 1;		// Display prompt
				cmdp = cmdbuf;
			} else if ((key == (char)0x08 || key == (char)0x7F) && cmdp > cmdbuf) { // Backspace
				cmdp--; // Move pointer back
				PRINT("\b \b"); // Erase last character on screen
			} else if (key == (char) 3) { // ^C
				cmdp = cmdbuf;
				PRINTLN("*CANCEL*");
				show_prompt = 1;
			} else if (cmdp < &cmdbuf[CMDLEN-1]) {
				*cmdp++ = key;
				putchar(key);
			}
		}
	}
	return 0;
}



const __flash struct zlpll_data default_chanel_config [MAX_CHANNELS]={
	{1022400000,0,0,1,0,0,0,0,0.0,0,0},
	{1195200000,0.0,1,0,0,0,0,0,0,0,0},
	{1173600000,0.0,1,0,0,0,0,0,0,0,0},
	{1264800000,0.0,1,0,0,0,0,0,0,0,0},
	{993600000 ,0.0,1,0,0,0,0,0,0,0,0},
	{1180800000,0.0,1,0,0,0,0,0,0,0,0},
	{561600000 ,0.0,1,0,0,0,0,0,0,0,0},
	{1036800000,0.0,1,0,0,0,0,0,0,0,0},
	{1036800000,0.0,1,0,0,0,0,0,0,0,0},
	{1036800000,0.0,1,0,0,0,0,0,0,0,0},
	{1036800000,0.0,1,0,0,0,0,0,0,0,0},
	{1036800000,0.0,1,0,0,0,0,0,0,0,0},
	{1036800000,0.0,1,0,0,0,0,0,0,0,0},
	{1036800000,0.0,1,0,0,0,0,0,0,0,0},
	{1036800000,0.0,1,0,0,0,0,0,0,0,0}
};


void default_config()
{
	uint8_t channel;
	struct zlpll_data rf;
	for (channel = 0;channel < MAX_CHANNELS;channel++)
	{
		memcpy_P(&rf, &default_chanel_config[channel],sizeof(rf));
		eeprom_write_block(&rf,(const char *) (EEPROM_CHAN + sizeof(rf)* channel) ,	sizeof(rf));
	}
}


	

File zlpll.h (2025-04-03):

/*
 * zlpll.h
 *
 *   Copyright (C) 2008-2022 Wanye Knowles ZL2BKC. 2023 Simon Eatough ZL2BRG
 *
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
 *   You should have received a copy of the GNU General Public License
 *   along with this program; if not, write to the Free Software
 *   Foundation, Inc., 675 Mass Ave, Cambridge, MA 02139, USA.
 */ 

#ifndef ZLPLL_H_
#define ZLPLL_H_


#include <stddef.h>
#include <stdlib.h>
#include <stdint.h>
#include <avr/io.h>

#define PACKED	__attribute__((__packed__))


#define ZLPLL_MAGIC		0x4002

#define ADF4351_DATA	PORTB,PB3		// aka MOSI in SPI mode
#define ADF4351_CLK		PORTB,PB5		// aka SCK
#define ADF4351_LE		PORTB,PB2		// aka SS

#define PIN_CHANSW	7
#define PIN_REFSEL	PINC2
#define PIN_AUXLED	PINB7

#define	AUXLED		PORTB,PB7
//#define LOCKLED		PORTD,PD5		// 4.0
#define LOCKLED		PORTB,PB6
#define LED1		PORTD,PD6
#define LED2		PORTD,PD7
#define PIN_TXD		PORTD,PD0
#define LOCKIN		PORTD,PD4
#define MUXOUTPIN	PORTD,PD5
#define REFSEL		PORTD,PD2
#define OSCPOWER	PORTD,PD3

#define DIAL_SW		PORTC,PC0
#define DIAL_PH1	PORTC,PC1
#define DIAL_PH2	PORTC,PC2

#define PWM_OC1A	PORTB,PB1	// PWM -> LPF -> TCXO Vc

#define ADC_EXTREFLEVEL	6		// ADC6 = detector for external ref


#define BAUD_RATE	9600

//  Print to console using format string in program memory.   Implicit newline in output
#define PRINTLN(fmt, args...) \
		do { printf_P(PSTR(fmt "\n"), ##args); } while (0)

//  Print to console using format string in program memory.
#define PRINT(fmt, args...) \
		do { printf_P(PSTR(fmt), ##args); } while (0)

#define DEBUG(module, fmt, args...) \
		do { if (debug_##module) printf_P(PSTR(fmt "\n"), ##args); } while (0)

#define DEBUG2(module, fmt, args...) \
		do { if (debug_##module) printf_P(PSTR(fmt), ##args); } while (0)
	
#define DEBUG_CHAR(module, c) \
		do { if (debug_##module) putchar(c); } while (0)

//  Macros to set or clear a bit
#define _SETBIT(PORT, BIT)		\
		do { (PORT) |= _BV(BIT); } while (0)

#define _CLRBIT(PORT, BIT)		\
		do { (PORT) &= ~_BV(BIT); } while (0)
	
#define _TGLBIT(PORT, BIT)		\
		do { (PORT) ^= _BV(BIT); } while (0)
			
#define DEBUG(module, fmt, args...) \
do { if (debug_##module) printf_P(PSTR(fmt "\n"), ##args); } while (0)

#define DEBUG_CHAR(module, c) \
do { if (debug_##module) putchar(c); } while (0)

// Variants for PORT,BIT specifications from macros
#define SET(PORTBIT)	_SETBIT(PORTBIT)
#define CLR(PORTBIT)	_CLRBIT(PORTBIT)
#define TGL(PORTBIT)	_TGLBIT(PORTBIT)

#define ISSET(PORTBIT)	(_GETBIT(PORTBIT))
#define ISCLR(PORTBIT)	(~(_GETBIT(PORTBIT)))

#define PIN(x) (*(&x - 2)) // Address Of Data Direction Register Of Port x
#define DDR(x) (*(&x - 1)) // Address Of Input Register Of Port x
#define PORT(x) (x)

#define _DDRSET(PORT, BIT)		\
		do { DDR(PORT) |= _BV(BIT); } while (0)

#define _DDRCLR(PORT, BIT)		\
		do { DDR(PORT) &= ~_BV(BIT); } while (0)

#define _GETBIT(PORT, BIT)		\
		(PIN(PORT) & _BV(BIT))
					
#define OUTPUT(PORTBIT)	_DDRSET(PORTBIT)
#define INPUT(PORTBIT)	_DDRCLR(PORTBIT)

typedef struct {
	uint32_t	freq;			// RF Output Frequnecy (in 10Hz steps)
	uint16_t	INT;
	uint16_t	MOD;
	uint8_t		RDIV;
	uint32_t	FRAC1;
	uint16_t    FRAC2;
	uint32_t	reg[16];
	uint32_t	ref;
	uint32_t	freqerr;
	int16_t		fsk_step;
	int8_t		fsk_offset;
	uint8_t		rf_mult;		// RF Multiplication factor (1=VCO Freq, 2=Doubler enabled)
	uint8_t		rf_div;			// RF Division factor (1=VCO Freq, 2 = /2, 4=/4 etc)
	uint8_t		rfA_enable;		// For ADF5355
	uint8_t		rfB_enable;		// For ADF5355
} PLL_t;

struct zlpll_data {
	uint32_t rf_freq;
	uint32_t	step;
	uint8_t	rdiv;
	uint8_t	level;
	uint8_t	mult;
	uint8_t mode;		// LO, Ext Key Beacon, RF Key Beacon
	uint8_t msg;;		// CW Beacon message number
	uint16_t spare1;
	uint16_t spare2;
	uint16_t spare3;
	uint16_t spare4;
};




union param_data {
	uint16_t    v;
	struct {
		/* LSB First */
		uint8_t	cp:4;    // Charge Pump
		uint8_t	mtld:1;  // Mute until lock detect
		uint8_t spur:1;  // Low Spur Mode=1, Low PN=0
		uint8_t doubler:1; // Disable doubler
	} p;
};

struct config_data {
	uint16_t	magic;
	uint32_t	spare;
	uint32_t	ext_ref;
	uint32_t	spare1;
	uint8_t		bleed;		
	uint8_t		max_doubler;	// Maximum doubler frequency
	uint8_t		charge_pump;
	uint8_t		mtld:1;
	uint8_t		spur:1;
	uint8_t		gcd:1;
	uint8_t		csr:1;
	
	uint8_t		cw_speed;	// wpm
	uint8_t		t1;			// ms
	uint8_t		t2;			// ms
	uint8_t		gap;
	uint8_t		spare2;	

#if PWM_ENABLE	
	uint16_t	pwmval;
	uint16_t	pwmtop;
#endif
#if _ADF4351
	uint16_t	maxmod;
	uint8_t		extlevel;
#endif
	
	uint8_t		i2c_addr;
};


#define SB(val,pos)	(((uint32_t)(val))<<(pos))

void default_config();

uint8_t check_pll_locked();
void cmd_channel(int ch);
void SPI_MasterTransmit(char cData);
uint16_t GCD(uint16_t a, uint16_t b);
void set_freq(uint32_t freq);

extern struct config_data cf;
extern struct zlpll_data  rf;
extern PLL_t	PLL;
extern uint8_t	debug_I2C;
extern uint8_t  debug_PLL;
extern uint8_t  debug_REF;
extern uint8_t  debug_CHAN;
extern uint8_t clkmode;


#define EEPROM_CONF		0		// EEPROM Location for configuration data

#define MUXOUT_TRISTATE	0
#define MUXOUT_DVDD		1
#define MUXOUT_DGND		2
#define MUXOUT_RDIV		3
#define MUXOUT_NDIV		4
#define MUXOUT_ALOCK	5
#define MUXOUT_DLOCK	6
#define MUXOUT_RESERVED	7



#endif /* ZLPLL_H_ */

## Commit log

2024-01-05 Added misc pre compiled binaries and documentation
    [ADF5355 Freq Plan.xlsx, Frequency Step calculator.xlsx, TPS560200 Calc.xlsx]
2024-01-24 Added pcb schmatics and board prints
2024-02-08 Added v4.1 kicad pcb
    [ZLPLL14G_1.kicad_sch, ZLPLL14G_2.kicad_sch, ZLPLL14G_V4.1.kicad_pcb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]
2024-04-07 Added V3.1B pcb
    [PLLv3.brd, PLLv3.sch]
2025-04-03 V4.4A Fixed frequency calculation issues by moving register calculation to fixed integer math
    [adf5355.c, config.h, menu.c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]
2025-12-02 Rev 4.4B Fixed reg6 divisor error, improved freq parsing
    [adf5355.c, config.h, zlpll.c]

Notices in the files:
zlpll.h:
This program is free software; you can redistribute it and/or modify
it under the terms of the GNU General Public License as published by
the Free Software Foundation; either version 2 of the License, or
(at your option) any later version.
